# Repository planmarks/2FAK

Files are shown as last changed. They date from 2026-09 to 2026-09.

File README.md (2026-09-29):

<div align="center">

# 2FAK

**Open-source USB-A security key — FIDO2 / WebAuthn, passkeys, and an optional on-board secure element.**

_by muru.global_







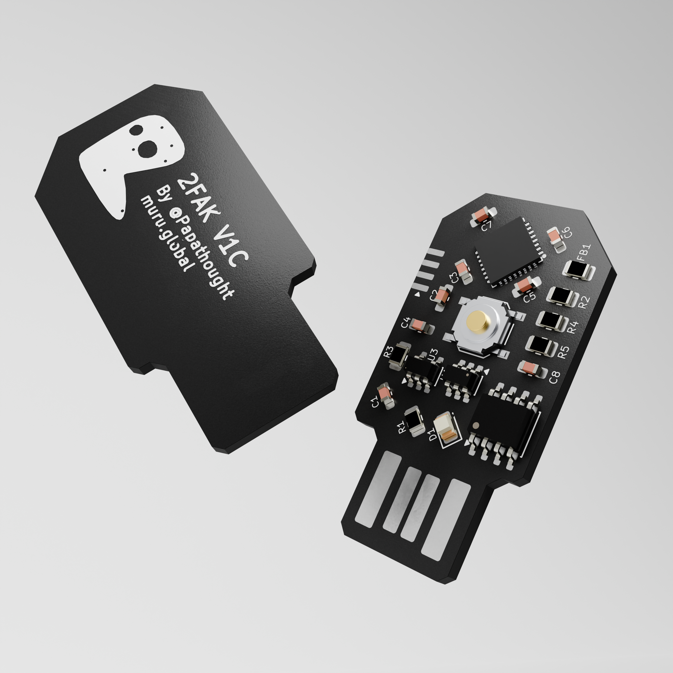
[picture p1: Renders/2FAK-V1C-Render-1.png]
2FAK V1C 3D render — front branding and populated back with the USB-A blade


<sub>2FAK V1C — the board <em>is</em> the USB-A plug: no cable, no moving connector.</sub>

</div>

---

2FAK is a small, affordable, fully open-source hardware security key. Plug it into any USB-A
port, tap the button, and you are signed in — the private keys are generated and kept on the
device and never leave it, so a fake login page or a stolen laptop gets nothing. It is built
on an STMicroelectronics **STM32L442KCU6** with an optional **ATECC608B** secure element.

- **USB VID/PID:** `0x1209 / 0x2FA2` (0x1209 is the pid.codes open-source Vendor ID; PID 0x2FA2 is registered to us)
- **AAGUID:** `c2aa81f8-352d-56e2-c689-2bfdb5a52ccc`
- **Firmware lineage:** fork of Nitrokey FIDO2 / SoloKeys solo1 (see `NOTICE`)

## Highlights

- 🔐 **Phishing-resistant** FIDO2 / WebAuthn — your login is bound to the real site.
- 🗝️ **Passkeys** — go fully passwordless on the Resident firmware (up to ~50 discoverable credentials).
- 🧩 **The board is the plug** — USB-A male blade, no cable, nothing to wear out.
- 🛡️ **Optional secure element** (ATECC608B) holds a device root that can't be read out.
- ✍️ **Signed USB firmware updates** + irreversible **RDP-2** debug lockdown on production units.
- 💻 **Doubles as a hardware SSH key** — see [Hardware SSH Keys](#hardware-ssh-keys).
- 📖 **Open source** (Apache-2.0) and **open hardware** — inspect everything.

<div align="center">
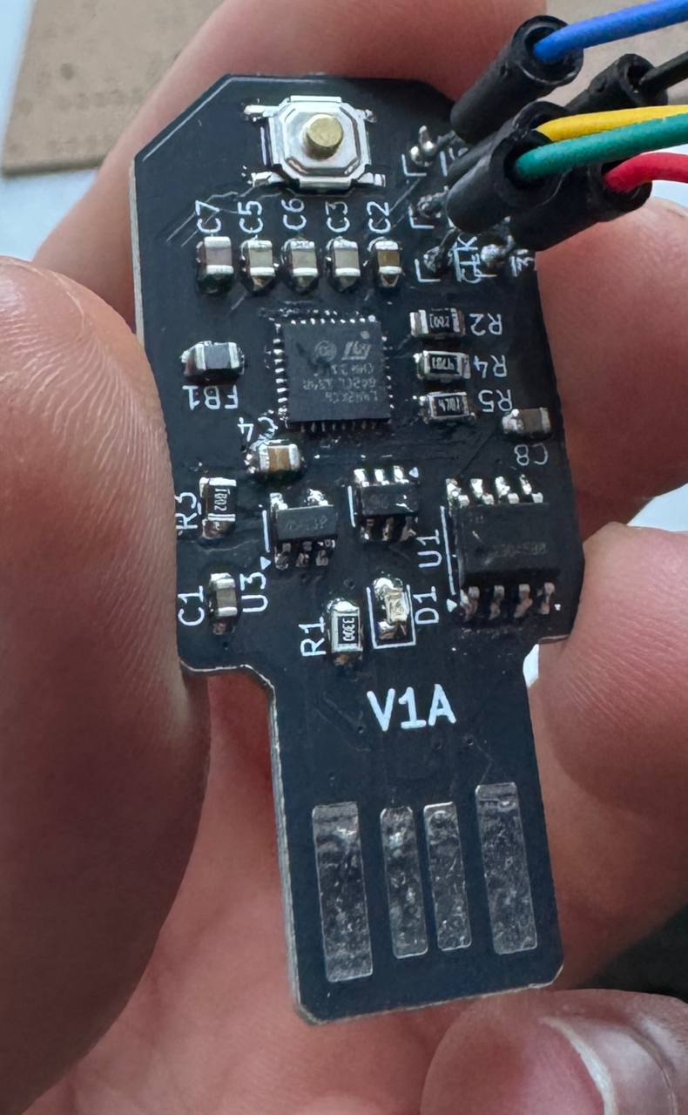
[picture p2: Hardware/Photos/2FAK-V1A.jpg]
2FAK V1A assembled board

<br><sub>Assembled 2FAK (V1A).</sub>
</div>

## Firmware editions

One board, two shipping firmware editions built from a single codebase:

| | **2FAK Secure** (Non-Resident) | **2FAK Passkey** (Resident) |
|---|---|---|
| Model | Second factor (server-side credentials) | Passkeys (discoverable credentials) |
| Discoverable credentials (rk) | No | Yes |
| Credential Management | No | Yes |
| ClientPIN protocols | 1 | 1 and 2 |
| Extensions | hmac-secret, credProtect | hmac-secret, credProtect, minPinLength |
| Conformance (self-test) | CTAP2.0, CTAP2.1 | CTAP2.0, CTAP2.1, CTAP2.3 |
| Hardware SSH keys | `ecdsa-sk` (non-resident) | `ecdsa-sk` incl. **resident/portable** |

Conformance is validated against the **FIDO Alliance Conformance Test Tools (self-test)** and
recorded per firmware under `Firmware/.../tests/`. Formal FIDO Certification is a separate
submission and is **not** claimed.

## Hardware

<div align="center">
<table>
<tr>
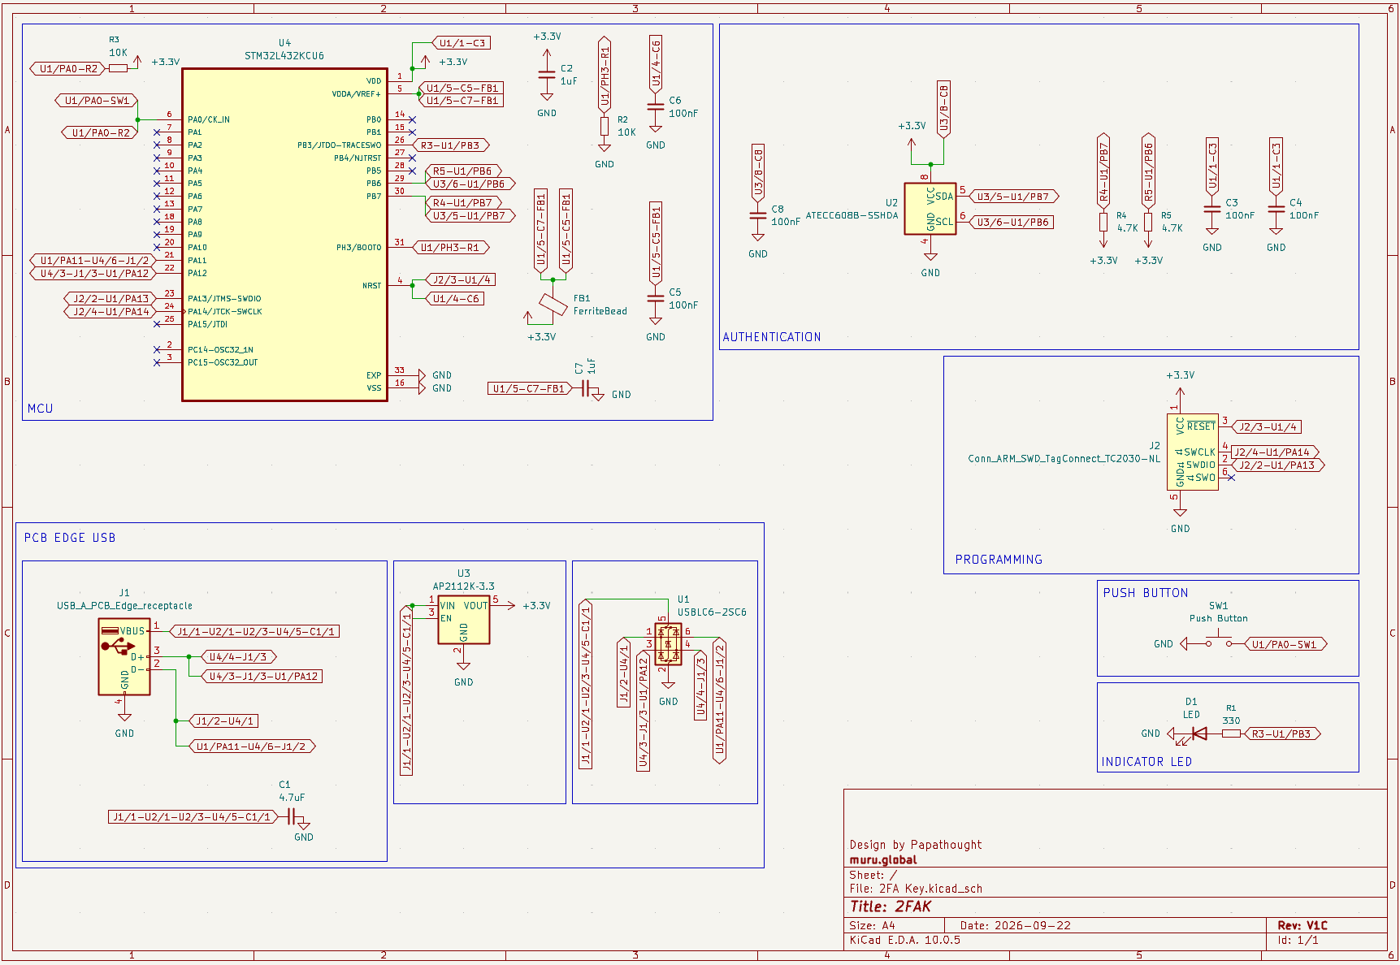
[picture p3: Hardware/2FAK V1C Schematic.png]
2FAK V1C schematic
<td align="center"><br><sub>Schematic (V1C)</sub></td>
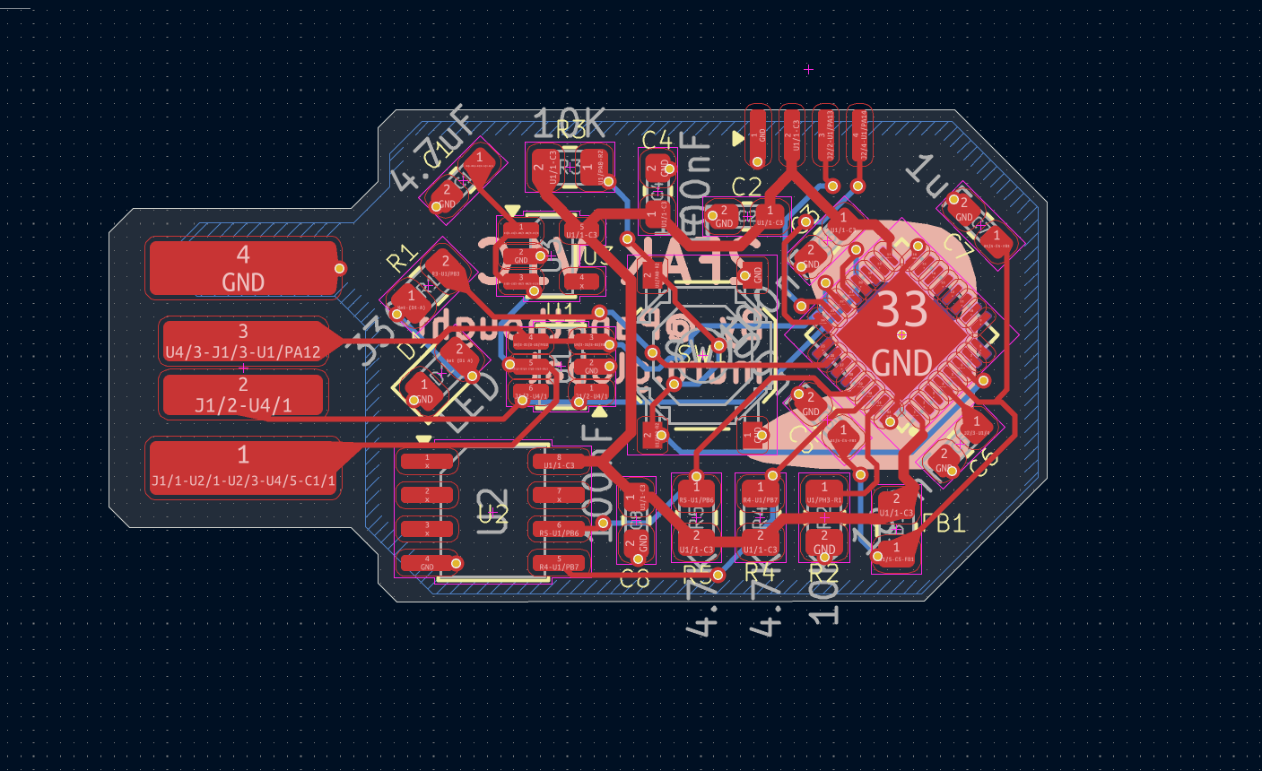
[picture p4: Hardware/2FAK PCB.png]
2FAK PCB layout / X-ray view
<td align="center"><br><sub>PCB layout — X-ray view (V1C)</sub></td>
</tr>
</table>
</div>

### At a glance

| | |
|---|---|
| **MCU** | STM32L442KCU6 — Arm Cortex-M4F, 80 MHz, UFQFPN-32; 256 KB flash / 64 KB SRAM |
| **Secure element** | Microchip ATECC608B on I2C1 (populated variant) |
| **Interface** | USB 2.0 Full-Speed, USB-A male blade (no cable) |
| **Protocols** | FIDO2 / WebAuthn, CTAP2.0 / 2.1 / 2.3 |
| **USB ID** | 0x1209 / 0x2FA2 (pid.codes) |
| **Controls** | Tactile touch button + status LED |
| **Power** | USB bus-powered, ~30 mA, no battery |
| **Size** | ~48 × 21 mm |

<details>
<summary><strong>Full hardware details & pinout</strong></summary>

#### Microcontroller

- **Part:** STM32L442KCU6 (Arm Cortex-M4F, up to 80 MHz, UFQFPN-32). Register-compatible
  with the STM32L432.
- **Memory:** 256 KB flash, 64 KB SRAM.
- **On-chip security:** true random number generator (TRNG), AES-256 hardware accelerator,
  and flash read-out protection (RDP) supported in silicon.
- **Clocking:** crystal-less USB using the internal HSI48 oscillator with the Clock Recovery
  System (CRS); no external crystal required.

#### Secure element (populated variant)

- **Part:** Microchip ATECC608B, on the I2C1 bus.
- Confirmed on hardware at 7-bit I2C address 0x60, Info revision word 0x00006003 (identifies
  an ATECC608B).
- Provides tamper-resistant key storage; on fitted units it holds a device root that cannot
  be read back out of the chip. On boards where it is not fitted, the footprint remains
  unpopulated.

#### USB / UI / power / debug

- USB 2.0 **Full-Speed** (12 Mbit/s) device; **USB-A male** contacts integrated into the PCB
  edge. Dedicated ESD / TVS protection on D+, D- and VBUS.
- One **tactile push button** (user presence) and one **status LED**.
- **USB bus-powered** from 5 V, regulated on-board to 3.3 V by an LDO. ~30 mA typical, no
  battery.
- **SWD** debug/programming (SWDIO / SWCLK); BOOT0 for boot-mode selection.

*Notice: SWD is closed in units sold as 2FAK Authentication Key.*

#### Pin summary

| Function | Pin |
|---|---|
| Button | PA0 |
| Status LED | PB3 |
| USB D- / D+ | PA11 / PA12 |
| SWD (SWDIO/SWCLK)| PA13 / PA14|
| I2C to ATECC (SCL/SDA) | PB6 / PB7 |
| BOOT0 | PH3 |

Note: PB6 / PB7 are shared between the ATECC I2C bus and an optional debug UART. On the
populated (secure-element) boards these pins are used for the I2C bus.

</details>

## Building

Each firmware directory is self-contained. On Windows with the STM32CubeIDE toolchain, from
Git Bash:

```bash
cd "Firmware/Resident CTAP2.3"
bash build.sh                    # production-style build
```

Build switches (environment variables) are documented in `build.sh`. Artifacts land in
`prebuilt/` and are **not** committed (see [Security](#security) below).

## Security

Per-credential keys are generated and held in the MCU; the optional device root can be held
in the ATECC608B secure element. Production units enable flash read-out protection (RDP) and
a verifying bootloader so firmware cannot be extracted or replaced off a locked device.

> **This is a public repository. It never contains private keys.** The following are
> git-ignored and must exist only on the build/flashing machines:
> - muru attestation private keys (`keys/2fak/ca_key.pem`, `att_key.pem`, `priv.bin/.hex`)
> - the production verifying-bootloader signing key
> - any provisioned `*.hex` (a provisioned image embeds the attestation private key)

Public certificates (root CA + leaf), the AAGUID, and the metadata statements are published
on purpose. Release firmware images are distributed via signed GitHub Releases, not committed
to the tree.

## Hardware SSH Keys

The **2FAK Passkey (Resident)** firmware doubles as a hardware-backed SSH key — no extra
firmware needed. SSH's `ecdsa-sk` key type rides on the standard FIDO2 flow, so the private
key stays on the 2FAK and every connection requires a physical touch.

```bash
ssh-keygen -t ecdsa-sk -O resident -O application=ssh:prod -f ~/.ssh/id_ecdsa_sk_prod
```

Because the key is *resident*, you can carry it on the token and pull it onto any machine
with `ssh-keygen -K` — handy for admins working across bastions and multiple workstations.
Add `-O verify-required` to also require the device PIN on privileged hosts. Requires OpenSSH
8.2+; uses ES256 (`ecdsa-sk`), not `ed25519-sk`.

Full sysadmin workflow — portable keys, ProxyJump bastions, Ansible `authorized_keys`, SSH-CA
integration, PIN tiering, Windows/PuTTY, backup enrollment, and the `2FAK-ssh-enroll` helper —
is in [`2FA Docs/2FAK Resident - Hardware SSH Key Guide.md`](2FA%20Docs/2FAK%20Resident%20-%20Hardware%20SSH%20Key%20Guide.md).

## Platform compatibility

Community/self-tested results. "not tested" simply means we haven't checked it yet.

<details>
<summary><strong>Show compatibility matrix</strong></summary>

| Platform | 2FAK Non-Resident | 2FAK Resident |
|---|---|---|
| Google | confirmed | confirmed |
| Microsoft | not supported | confirmed |
| Apple ID | not supported* | not supported* |
| Amazon | not supported | confirmed |
| Facebook / Meta | not tested | not tested |
| X | not tested | not tested |
| GitLab | not supported | confirmed |
| AWS (IAM / root) | unknown error* | unknown error* |
| Cloudflare | confirmed | confirmed |
| Okta | not tested | not tested |
| Bitwarden | not tested | not tested |
| 1Password | not tested | not tested |
| PayPal | not tested | not tested |
| Stripe | not supported | confirmed |
| Coinbase | not tested | not tested |
| Kraken | not tested | not tested |
| Binance | not tested | not tested |
| Dropbox | confirmed | confirmed |
| Proton (Mail) | confirmed | confirmed |
| Fastmail | confirmed | confirmed |
| Nextcloud | not tested | not tested |
| Discord | confirmed | confirmed |
| Salesforce | not tested | not tested |

<sub>* Apple ID and AWS entries reflect platform-side behaviour we're still investigating.</sub>

</details>

## Other firmware options

The programmable (no-secure-element) board can also run:

- Mouse Jiggler firmware *(coming soon)*
- HID Injection firmware *(coming soon)*

## License

Licensed under **Apache-2.0**. See [`LICENSE-APACHE`](LICENSE-APACHE) for the full license
text and `NOTICE` for third-party attribution.

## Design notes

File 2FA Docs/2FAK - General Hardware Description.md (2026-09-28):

# 2FAK - General Hardware Description

General description of the 2FAK hardware platform. This document covers the hardware only;
it makes no reference to firmware or firmware behaviour.

## Overview

2FAK is a small open-source USB-A hardware token. The printed circuit board itself forms
the USB-A plug (a single-piece "blade"), so there is no cable and no separate connector to
wear out. It is built around an STMicroelectronics STM32L4 microcontroller and is powered
entirely from the USB port.

The same board is produced in two hardware configurations:

- **With secure element** - the ATECC608B is populated. Used for the pre-programmed
  security-key units.
- **Without secure element** - the ATECC608B footprint is left unpopulated. Used for the
  programmable units.

Both configurations are otherwise identical.

## Microcontroller

- **Part:** STMicroelectronics STM32L442KCU6 (Arm Cortex-M4F, up to 80 MHz, UFQFPN-32
  package). Register-compatible with the STM32L432.
- **Memory:** 256 KB flash, 64 KB SRAM.
- **On-chip security features:** true random number generator (TRNG), AES-256 hardware
  accelerator, and flash read-out protection (RDP) supported in silicon.
- **Clocking:** crystal-less USB using the internal HSI48 oscillator with the Clock
  Recovery System (CRS); no external crystal is required.

## Secure element (populated variant)

- **Part:** Microchip ATECC608B, on the I2C1 bus.
- Confirmed on hardware at 7-bit I2C address 0x60, Info revision word 0x00006003 (which
  identifies an ATECC608B).
- Provides tamper-resistant key storage and cryptographic operations. On the units where
  it is fitted, it can hold a device root that cannot be read back out of the chip.
- On boards where it is not fitted, the footprint remains but is unpopulated.

## USB interface

- USB 2.0 **Full-Speed** (12 Mbit/s) device.
- **USB-A male** contacts integrated into the edge of the PCB (no cable, no moving
  connector).
- Dedicated ESD / TVS protection on the D+, D- and VBUS lines.

## User interface

- One **tactile push button** (user-presence / control input).
- One **status LED**.

## Power

- **USB bus-powered** from the 5 V supply, regulated on-board to 3.3 V by an LDO.
- Typical current draw about 30 mA. No battery and no battery sensing.

## Debug and programming

- **SWD** debug/programming interface (SWDIO / SWCLK), broken out to a Tag-Connect
  TC2030-style footprint for factory and advanced use.
- BOOT0 is available for boot-mode selection.

## Pin summary

| Function | Pin |
|---|---|
| Button | PA0 |
| Status LED | PB3 |
| USB D- / D+ | PA11 / PA12 |
| SWD (SWDIO/SWCLK)| PA13 / PA14|
| I2C to ATECC (SCL/SDA) | PB6 / PB7 |
| BOOT0 | PH3 |

Note: PB6 / PB7 are shared between the ATECC I2C bus and an optional debug UART. On the
populated (secure-element) boards these pins are used for the I2C bus.

## Board

- 2-layer FR4, ground-poured.
- Approximately 48 x 21 mm.
- Gold-plated USB edge contacts.
- Hardware revision V1A.

## Operating conditions

- Works in any standard USB-A port. Driver-free at the hardware level (enumeration and
  behaviour are determined by whatever firmware is loaded, which is out of scope here).

*Hardware revision V1A. Specifications may change.*

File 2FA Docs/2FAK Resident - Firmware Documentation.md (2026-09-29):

# 2FAK Resident - Firmware Documentation

Documentation of the **resident (passkey)** firmware. This document covers the firmware only.
It is one of two firmware variants built from a single codebase; the second-factor variant is
documented in `2FAK Non-Resident - Firmware Documentation.md`. This variant is the same code
built with `RESIDENT=1` (and `FIDO23=1`).

## Summary

A FIDO2 / WebAuthn security-key firmware that supports **discoverable credentials (passkeys)**
and on-device **credential management**, for passwordless sign-in. It is a fork of the Nitrokey
FIDO2 firmware, which derives from SoloKeys Solo 1.

- **Transport:** USB HID (CTAPHID).
- **USB identity:** VID 0x1209 (pid.codes, open-source) / PID 0x2FA2.
- **AAGUID:** c2aa81f8-352d-56e2-c689-2bfdb5a52ccc (self-assigned).
- **Conformance:** passes the FIDO Alliance Conformance Test Tools for CTAP2.0, CTAP2.1 and
  CTAP2.3 (self-test). See `2FAK Resident - FIDO Conformance Readiness.md`.
- **License:** Apache-2.0.

## Protocols advertised (authenticatorGetInfo)

- **versions:** `FIDO_2_0`, `FIDO_2_1_PRE`, `FIDO_2_1`, `FIDO_2_3`.
- **extensions:** `credProtect`, `hmac-secret`.
- **options:** `rk = true`, `up = true`, `plat = false`, `credMgmt = true`, `clientPin`
  (dynamic), `pinUvAuthToken = true`. Emitted in CTAP2 canonical key order.
- **pinUvAuthProtocols:** `[1, 2]`.
- **transports:** `["usb"]`.
- **algorithms:** ES256 (`-7`).
- **maxCredentialCountInList**, **maxCredentialIdLength**, **minPINLength** (4),
  **firmwareVersion**.

## Credential model

- **Resident / discoverable credentials (passkeys).** `authenticatorMakeCredential` with
  `rk = true` stores the credential on the device so it can be found later by a
  getAssertion with an empty allow-list (passwordless sign-in). Capacity is up to
  approximately **50 resident credentials**.
- Discoverable credentials are flagged inside the (MAC-covered) credential ID. Once a
  discoverable credential is deleted via credential management, a getAssertion that presents
  its credential ID in an allow-list correctly fails with `NO_CREDENTIALS` (a deleted passkey
  cannot be resurrected).
- Non-discoverable (second-factor) credentials also work, exactly as in the non-resident
  variant.

## CTAP commands

- Everything in the non-resident variant, plus:
- `authenticatorCredentialManagement` (0x0A / preview 0x41): `getCredsMetadata`,
  `enumerateRPs` (Begin/GetNextRP), `enumerateCredentials` (Begin/GetNextCredential),
  `deleteCredential`, and `updateUserInformation`.
- `authenticatorSelection` (0x0B).
- **Client PIN:** PIN/UV auth protocols **1 and 2**, including
  `getPinUvAuthTokenUsingPinWithPermissions`.
- **pinUvAuthToken:** 32-byte token; permission bits makeCredential + getAssertion +
  **credentialManagement** (`mc`, `ga`, `cm`); optional RP-ID binding; rolling ~30 s
  inactivity lifetime; invalidated on power cycle and reset. Credential-management commands
  require a token carrying the `cm` permission; a token without it is rejected with
  `PIN_AUTH_INVALID`.

## Client PIN behaviour

- Same as the non-resident variant: optional by default, with build-time `PIN_POLICY`
  (`optional` / `requireset` / `alwaysuv`). Standard CTAP retry handling (per-boot lockout at
  3 consecutive failures, full block at zero retries; a reset clears both).

## User presence

- A physical button press is required for registration, authentication, and
  `authenticatorSelection`, with LED signalling.

## Extensions

- **hmac-secret** (protocol 1 and 2 aware).
- **credProtect** (credential-protection levels; the level is also reported through
  credential management).

## Hardware SSH keys (OpenSSH)

Because SSH's FIDO key types ride on the standard FIDO2 credential flow, this firmware works
as a hardware-backed SSH key with **no firmware changes**:

- OpenSSH 8.2+ `ecdsa-sk` keys use ES256, which is exactly what this firmware advertises;
  the FIDO application string `ssh:` is treated as an ordinary RP ID (no RP-ID filtering).
- **Resident (portable) SSH keys** (`ssh-keygen -t ecdsa-sk -O resident`) are supported
  because this variant stores discoverable credentials; they can be pulled onto any machine
  with `ssh-keygen -K`. The non-resident variant can only do non-resident `ecdsa-sk` keys.
- `verify-required` maps to the device PIN (Client PIN) plus the touch (user presence).
- `ed25519-sk` is **not** supported (no Ed25519/EdDSA in the firmware); use `ecdsa-sk`.

Full sysadmin workflow (resident enroll/export, ProxyJump bastions, Ansible
`authorized_keys`, SSH-CA integration, PIN tiering, Windows/PuTTY, backup enrollment, and
the `2FAK-ssh-enroll` helper) is documented in `2FAK Resident - Hardware SSH Key Guide.md`.

## Attestation

- Packed / `basic_full` attestation, muru.global batch attestation key + certificate on
  production units (injected by `provision_attestation.py`); metadata statement embeds the
  muru Root CA. Not FIDO Certified; conformance is a self-test result; not (yet) in the FIDO
  Metadata Service.

## Secure firmware update, production lockdown, and hardware root

These are identical to the non-resident variant:

- **Signed USB update:** the verifying (production) bootloader accepts only muru-signed
  firmware (ECDSA P-256 over the app region); the dev bootloader accepts unsigned firmware;
  anti-rollback enforces version-not-older.
- **Production lockdown:** RDP-2 permanently disables the debug port; signed USB updates still
  work afterwards; production images are built without `SOLO_HACKER`.
- **Hardware root of trust:** on units with a provisioned ATECC608B the FIDO master secret is
  derived inside the secure element, with a transparent software fallback if the chip is
  absent, unprovisioned, or fails.

(See `2FAK Non-Resident - Firmware Documentation.md` for the detailed description of these
shared subsystems.)

## Build (reference)

- `RESIDENT=1 FIDO23=1 bash build.sh` selects the passkey behaviour and advertises `FIDO_2_3`
  (default for this variant).
- `VERIFY_BOOT=1` produces the production image (`all-verifying.hex`); `VERIFY_BOOT=0`
  produces the dev image (`all-dev.hex`).
- Toolchain: arm-none-eabi-gcc + make from the STM32CubeIDE bundle. Flash region use is
  roughly one third of the 256 KB device.

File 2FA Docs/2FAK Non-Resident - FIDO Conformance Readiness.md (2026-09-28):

# 2FAK Non-Resident - FIDO Conformance Readiness

Status of the Non-resident firmware against the FIDO Alliance Conformance Testing Tools
and the Metadata Statement spec (v3.0). For the team.

## STATUS: CTAP2.0 and CTAP2.1 authenticator tests PASS

Using `prebuilt/all_conformance.hex` + `metadata/2fak_metadata.json`, the FIDO
Conformance Tools v1.9.2 CTAP2.0 and CTAP2.1 authenticator suites pass for the
non-resident profile (resident-key / enterprise / largeBlob / credMgmt / authrConfig /
bioEnroll modules are out of scope for this SKU and not selected). This is self-test
validation, not formal FIDO certification. Remaining work is administrative (see end).

## What the tools actually check

1. CTAP2 authenticator conformance - tests the device against the CTAP spec, up to the
   highest version it advertises in getInfo.
2. Metadata Statement validation - checks the statement is well-formed and that its claims
   (algorithms, attestation, key protection, AAGUID) match the device, and that device
   attestation chains to the declared `attestationRootCertificates`.

Formal certification and Metadata Service (MDS) listing are a separate, paid FIDO
process. The tools themselves can be used for self-testing.

## Done in firmware / tooling

- CTAP2 command set: GetInfo, MakeCredential, GetAssertion, ClientPIN, Reset; extensions
  hmac-secret and credProtect; non-resident model (rk=false, resident requests rejected).
- PIN/UV Auth Protocol 1 and 2; pinUvAuthToken permissions model
  (getPinUvAuthTokenUsingPinWithPermissions, mc/ga permission bits, RP-ID binding,
  rolling expiry). Validated on hardware.
- 2.3 getInfo fields present: algorithms, minPINLength, firmwareVersion, pinUvAuthToken,
  transports, maxCredentialCountInList, maxCredentialIdLength.
- **Version advertisement is now a build switch.** Default tops out at `FIDO_2_1` (which
  we conform to). `FIDO23=1` additionally advertises `FIDO_2_3`. This matters because the
  tools test to the highest advertised version: shipping FIDO_2_3 before full 2.3
  conformance would fail.
- **Attestation PKI created.** `keys/make_attestation_ca.py` builds a self-signed
  attestation Root CA and a batch leaf certificate. The leaf carries the AAGUID extension
  (1.3.6.1.4.1.45724.1.1.4) equal to the device AAGUID `c2aa81f8-352d-56e2-c689-2bfdb5a52ccc`,
  Basic Constraints CA:FALSE, OU="Authenticator Attestation". Chain verifies. This fixes
  the earlier bug where the leaf cert's AAGUID did not match getInfo.
- **Metadata statement drafted.** `metadata/make_metadata.py` emits
  `metadata/2fak_metadata.json` (schema 3), mirroring the default build's getInfo and
  embedding the Root CA in `attestationRootCertificates`.

## Required Metadata Statement fields - status

| Field | Status |
|---|---|
| protocolFamily, schema, upv | done (fido2, 3, [1.0, 1.1]) |
| description, authenticatorVersion | done |
| authenticationAlgorithms, publicKeyAlgAndEncodings | done (ES256, cose) |
| attestationTypes | basic_full |
| userVerificationDetails | presence_internal / passcode_internal |
| keyProtection, matcherProtection | hardware / on_chip |
| tcDisplay, attachmentHint, cryptoStrength | done |
| aaguid | done, consistent across firmware + cert + statement |
| attestationRootCertificates | done (real Root CA) |
| authenticatorGetInfo | mirrors default build |
| legalHeader | present, but ACCEPTING it is a vendor legal decision (see below) |

## Conformance-blocking work - now DONE

1. **Real attestation provisioned.** `provision_attestation.py` injects the muru batch leaf
   cert (chaining to the Root CA embedded in the metadata) so device attestation validates.
   Production units ship attested; the dev image no longer relies on the Solo "hacker" key.
2. **CTAP2 conformance tools run and passing.** The CTAP2.0 and CTAP2.1 authenticator suites
   pass for this SKU (self-test) using `prebuilt/all_conformance.hex` + the metadata
   statement. The run history (error codes, option matrix, CBOR canonical encoding,
   absent-feature responses, PIN code-point length) is in the "run" sections below.
3. **PIN policy.** Shipped default is `optional` (build-time `PIN_POLICY`); metadata
   `userVerificationDetails` matches (presence + passcode).

## Vendor / business steps

- **USB VID/PID registered:** VID 0x1209 (pid.codes) / PID 0x2FA2. The pid.codes
  allocation PR has been approved and merged, so PID 0x2FA2 is officially recorded to us.
- Keeping `keys/2fak/ca_key.pem` (the attestation Root CA private key) safe and backed
  up. It is gitignored. Losing it means re-issuing the CA and re-provisioning devices.
- Accepting the FIDO `legalHeader` terms and creating a FIDO account - only needed for the
  paid path below.
- Formal FIDO certification + MDS submission (the paid path) and, if desired, registering
  the AAGUID - planned for later, not required to ship.

## For full CTAP 2.3 (optional, later)

Before enabling `FIDO23=1` for shipping: implement the remaining 2.3 items
(alwaysUv/makeCredUvNotRqd handling as advertised, full up/uv option matrix,
authenticatorConfig / setMinPINLength if claimed) and pass the 2.3 conformance profile.

## First CTAP2.0 conformance run (findings + fixes)

First run: 23 pass / 25 fail. Root causes and fixes:

1. **authenticatorReset 10-second window (caused ~9 failures).** The tool resets the
   authenticator programmatically in most "before all" hooks; our production firmware only
   allows Reset within 10s of power-up, so later resets returned CTAP2_ERR_NOT_ALLOWED and
   cascaded. FIX: `CONFORMANCE=1` build flag lifts the window (reset allowed any time,
   touch still required). Use `prebuilt/all_conformance.hex` for testing; production keeps
   the 10s window.
2. **Metadata P-22 attachmentHint** - "external" must be combined with a transport flag.
   FIX: now `["external", "wired"]`.
3. **Metadata P-29 icon** - the tool requires an `icon`. FIX: a valid PNG data URL is now
   generated.
4. **authenticatorGetInfo deep-equality** - metadata must match the device getInfo exactly.
   FIX: added `maxCredentialCountInList` (20) and `maxCredentialIdLength` (128).
5. **HIDFORK TIMEOUT / "Sequence out of order"** - the tool's own node-HID transport on
   Windows, not the device: python-fido2 (a strict implementation) drives the same device
   flawlessly. Mitigations: direct USB port (no hub), close every other app using the key
   (browser, our python scripts, Windows "Security key" settings), and if Windows stays
   flaky run the conformance tool on Linux. The reset fix also clears hung states between
   groups, which removes many secondary timeouts.

Re-test with `prebuilt/all_conformance.hex` flashed and the regenerated
`metadata/2fak_metadata.json` loaded.

## Second run (31 pass / 34 fail) - findings + fixes

The reset fix + metadata fixes worked (getInfo, metadata statement, user-entity checks
now pass). New/remaining:

1. **User presence timeouts (biggest, ~15 failures).** The tool issues many
   makeCredential/getAssertion ops; each waited for a physical touch, timed out
   (HIDFORK TIMEOUT), and left the channel busy (CTAP1_ERR_CHANNEL_BUSY cascade on the
   following F-tests). FIX: the CONFORMANCE build now auto-approves user presence
   (`ctap2_user_presence_test` returns success immediately) so the suite runs unattended.
   Production still requires a real touch.
2. **Metadata P-3 passcode_external.** For a ClientPin authenticator the tool requires a
   userVerificationDetails entry of `passcode_external` (the PIN is entered on the client
   and sent to the authenticator). FIX: changed `passcode_internal` -> `passcode_external`.
3. **Resident-key / CredProtect tests will still fail - expected.** The selected "Full
   feature profile" creates *discoverable credentials*; this is a non-resident device
   (`rk=false`), so those return CTAP2_ERR_UNSUPPORTED_OPTION. Select the profile WITHOUT
   Discoverable Credentials, or accept that RK/credProtect-on-RK tests do not apply to
   this SKU. Passing them would require the Resident firmware variant.
4. **"Sequence out of order" on getKeyAgreement (2 groups).** Under investigation; the
   same command works perfectly via python-fido2, so it is likely the tool's node-HID
   transport. Re-check after the auto-UP fix clears the channel-busy cascade.

## Third run (108 pass / 9 fail) - findings + fixes

Huge jump. The 9 remaining, categorized:

- **HID-1 P-10 (keepalive / cancel) - FIXED** via `SKIP_BUTTON_CHECK_WITH_DELAY`
  (CONFORMANCE_BUILD): emits keepalives and honours CTAPHID_CANCEL for ~500ms, then
  auto-approves.
- **HID-1 P-11 (getAssertion invalid credId -> keepalive then NO_CREDENTIALS) - FIXED in
  logic.** getAssertion returned NO_CREDENTIALS *before* the user-presence step, so no
  keepalive was emitted (SKIP_WITH_DELAY alone did not help because UP was never reached).
  Now a user-presence test runs before returning NO_CREDENTIALS (emits the keepalive and
  avoids credential-existence timing leaks).
- **CredProtect P-1/P-2/P-3 - not applicable to this SKU.** They create *discoverable
  credentials*; this is non-resident (`rk=false`) so they return
  CTAP2_ERR_UNSUPPORTED_OPTION. Select the profile WITHOUT Discoverable Credentials.
  These cannot pass without the Resident firmware variant.
- **ClientPin GetRetries P-3 - procedural.** The test exhausts PIN retries to reach
  CTAP2_ERR_PIN_BLOCKED (0x32). Our per-boot lockout returns 0x34 after 3 wrong attempts
  and requires a real power cycle to continue (both behaviours are CTAP-mandated and P-2,
  which needs 0x34, passes). When the tool prompts after 0x34 during THIS test, physically
  unplug/replug so it can continue to 0x32.
- **3 x "Timeout of 30000ms" (MakeCred-Req-3, GetAssertion-Req-3, Reset-1 before-all
  hooks) - likely intermittent HID.** No CTAP error was returned; the hook hung. Re-check
  after the keepalive fix (device stays responsive during UP) and with a clean HID
  environment. If they persist, capture which command hangs.

## CTAP2.1 run - findings + fixes

CTAP2.0 fully passed. CTAP2.1 findings (all fixed in firmware; general 2.1 correctness,
in both default and conformance builds):

1. **authenticatorSelection (0x0B) - implemented.** Was unhandled (P-15 got no keepalive).
   Added the command: it runs a user-presence check (keepalive + CANCEL), returns OK on
   touch / KEEPALIVE_CANCEL on cancel.
2. **makeCredential up=true rejected -> accepted.** We advertise the `up` option, so the
   tool sends makeCredential with up=true and expects success. We now accept explicit
   up=true (reject only up=false).
3. **hmac-secret not PIN-protocol-2 aware -> fixed.** getAssertion hmac-secret returned
   INVALID_LENGTH under protocol 2 (48/80-byte saltEnc with IV). The extension is now
   protocol-aware: HKDF shared secret, 32-byte saltAuth, IV strip on decrypt, IV prepend
   on the encrypted output. Struct/parser widened to 80 bytes + a pinProtocol field.
4. **hmac-secret wrong-type accepted -> rejected.** makeCredential with a non-boolean
   hmac-secret now returns CTAP2_ERR_INVALID_CBOR_TYPE (F-1).

Second CTAP2.1 pass - further findings + fixes:

5. **hmac-secret protocol-2 two-salt output overflowed the getAssertion extensions
   buffer (INVALID_CBOR).** The buffer was 80 bytes; a protocol-2 two-salt output encodes
   to ~95 bytes (IV+64+CBOR). Enlarged `getAssertionState.buf.extensions` to 128. Fixes
   HMAC-Secret P-3 (which also sends a two-salt request) and P-4.
6. **Metadata P-36 legalHeader.** MDS3 requires the exact string "Submission of this
   statement ... https://fidoalliance.org/metadata/metadata-legal-terms/." (not the URL).
   Fixed in make_metadata.py.
7. **ClientPin F-4 (min PIN length by code points) - FIXED.** On a clean run this was a
   real defect: our PIN length check was byte-based, so a 3-code-point multi-byte PIN
   (>= 4 bytes) was wrongly accepted and set, and a follow-up setPIN then returned
   NOT_ALLOWED. CTAP requires a minimum of 4 Unicode CODE POINTS. ctap_update_pin_if_verified
   now counts code points (skipping UTF-8 continuation bytes) and rejects < 4 with
   PIN_POLICY_VIOLATION. Applies to both protocol 1 and 2.

Environmental / procedural (not firmware): "Waited too long to connect" and "FORCED
TERMINATION" are the HID transport / a manual stop; the PIN-retry test still needs
physical replugs to reach 0x32.

## Images

- `prebuilt/all.hex` - production default (FIDO_2_1, reset-restricted).
- `prebuilt/all_attested.hex` - production default + muru attestation.
- `prebuilt/all_conformance.hex` - CONFORMANCE build (reset any time) + attestation. Flash
  this for the FIDO conformance tools. **Do not ship it.**

## Reproduce

    python keys/make_attestation_ca.py       # one-time: create the attestation CA
    python metadata/make_metadata.py         # regenerate the metadata statement
    bash build.sh                            # default: FIDO_2_1, U2F off, PIN optional
    python provision_attestation.py prebuilt/all.hex prebuilt/all_attested.hex

    # Conformance-test image (reset allowed any time) + attestation:
    CONFORMANCE=1 bash build.sh
    python provision_attestation.py prebuilt/all.hex prebuilt/all_conformance.hex
    bash build.sh                            # rebuild the production default afterwards

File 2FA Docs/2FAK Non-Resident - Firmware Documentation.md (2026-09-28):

# 2FAK Non-Resident - Firmware Documentation

Documentation of the **non-resident (second-factor)** firmware. This document covers the
firmware only. It is one of two firmware variants built from a single codebase; the passkey
variant is documented in `2FAK Resident - Firmware Documentation.md`.

## Summary

A FIDO2 / WebAuthn security-key firmware configured as a **second factor only**. It creates
non-discoverable (server-side) credentials and declines requests to store resident /
discoverable credentials. It is a fork of the Nitrokey FIDO2 firmware, which derives from
SoloKeys Solo 1, and is built with the `RESIDENT=0` option.

- **Transport:** USB HID (CTAPHID).
- **USB identity:** VID 0x1209 (pid.codes, open-source) / PID 0x2FA2.
- **AAGUID:** c2aa81f8-352d-56e2-c689-2bfdb5a52ccc (self-assigned).
- **Conformance:** passes the FIDO Alliance Conformance Test Tools for CTAP2.0 and CTAP2.1
  (self-test). See `2FAK Non-Resident - FIDO Conformance Readiness.md`.
- **License:** Apache-2.0.

## Protocols advertised (authenticatorGetInfo)

- **versions:** `FIDO_2_0`, `FIDO_2_1_PRE`, `FIDO_2_1` (this variant does not advertise
  `FIDO_2_3`).
- **extensions:** `credProtect`, `hmac-secret`.
- **options:** `rk = false`, `up = true`, `plat = false`, `clientPin` (dynamic, reflects
  whether a PIN is set), `pinUvAuthToken = true`. No `credMgmt`.
- **pinUvAuthProtocols:** `[1, 2]`.
- **transports:** `["usb"]`.
- **algorithms:** ES256 (`-7`).
- **maxCredentialCountInList**, **maxCredentialIdLength**, **minPINLength** (4),
  **firmwareVersion**.

## Credential model

- **Non-resident only.** `authenticatorMakeCredential` returns
  `CTAP2_ERR_UNSUPPORTED_OPTION` when a resident/discoverable credential (`rk = true`) is
  requested. Nothing is stored on the key and there is no account picker; the number of
  accounts is effectively unlimited because credentials live on the relying party.
- Credentials are self-authenticating: the credential ID carries a MAC that the device
  verifies, so per-account key pairs are re-derived on demand and never exported.

## CTAP commands

- `authenticatorGetInfo`, `authenticatorMakeCredential`, `authenticatorGetAssertion`,
  `authenticatorClientPIN`, `authenticatorReset`, plus the Solo/Nitrokey vendor commands
  (bootloader entry, version, lock, ATECC self-test).
- **Client PIN:** PIN/UV auth protocols **1 and 2**, including
  `getPinUvAuthTokenUsingPinWithPermissions`.
- **pinUvAuthToken:** 32-byte token; permission bits limited to makeCredential + getAssertion
  (`mc`, `ga`); optional RP-ID binding; rolling ~30 s inactivity lifetime; invalidated on
  power cycle and on reset. A token presented without the permission an operation needs is
  rejected with `PIN_AUTH_INVALID`.

## Client PIN behaviour

- Optional by default (the relying party decides). A build-time `PIN_POLICY` can change this:
  `optional` (default), `requireset` (a PIN must be set before the first credential), or
  `alwaysuv` (advertise `alwaysUv` and require a pinUvAuthToken on every operation).
- Standard CTAP retry handling: a per-boot lockout after 3 consecutive bad attempts
  (`PIN_AUTH_BLOCKED`, cleared by a power cycle), and a full block when the persistent retry
  counter reaches zero (`PIN_BLOCKED`, cleared only by an authenticatorReset). A reset also
  clears the per-boot lockout.

## User presence

- A physical button press is required for registration and authentication (user presence),
  with LED signalling (idle off, waiting blink, accepted solid).

## Extensions

- **hmac-secret** (protocol 1 and 2 aware).
- **credProtect** (credential-protection levels, packed into the MAC-covered credential ID).

## Attestation

- Packed / `basic_full` attestation.
- Development images seed the well-known Solo "hacker" attestation key. Production units are
  provisioned with the muru.global batch attestation key + certificate (injected at flash
  time by `provision_attestation.py`); the metadata statement embeds the muru Root CA.
- The device uses self-/batch attestation and is not (yet) listed in the FIDO Metadata
  Service. It is not FIDO Certified; conformance is a self-test result.

## Secure firmware update over USB

- **Verifying (production) bootloader:** accepts firmware over USB only if it is signed with
  the muru production bootloader key (ECDSA P-256 over a SHA-256 of the application region).
  The private key never leaves muru; the device verifies the signature itself.
- **Non-verifying (dev) bootloader:** accepts unsigned firmware, for development.
- **Anti-rollback:** the verifying bootloader only accepts firmware whose version is greater
  than or equal to the currently installed version.
- Updates are delivered over USB (no programmer needed), so a unit remains updatable after
  its debug port is closed.

## Production lockdown

- Production units enable **flash read-out protection level 2 (RDP-2)**: the SWD/debug port
  is permanently disabled, so firmware and secrets cannot be read out or the chip reflashed
  over a programmer. Signed USB updates still work after locking, because the bootloader
  remains intact.
- Production images are built without the `SOLO_HACKER` option.

## Hardware root of trust (populated units)

- On units with the ATECC608B fitted and provisioned, the FIDO master secret is derived
  inside the secure element (MAC command, mode 0x06) from an unreadable root key, rather than
  held only in MCU flash. Per-credential keys derive from that master secret.
- If the secure element is absent, unprovisioned, or ever fails to derive, the firmware falls
  back to a software master secret with no change in behaviour, so a missing or mis-provisioned
  chip cannot break the FIDO function.
- An authenticatorReset changes the per-device salt, which invalidates all previously derived
  credentials.

## Build (reference)

- `RESIDENT=0 bash build.sh` selects the non-resident behaviour (default for this variant).
- `VERIFY_BOOT=1` produces the production image (`all-verifying.hex`, verifying bootloader,
  `SOLO_HACKER` off); `VERIFY_BOOT=0` produces the dev image (`all-dev.hex`).
- `U2F=1` optionally compiles the legacy U2F/CTAP1 path (off by default to save flash).
- Toolchain: arm-none-eabi-gcc + make from the STM32CubeIDE bundle. Flash region use is
  roughly one third of the 256 KB device.

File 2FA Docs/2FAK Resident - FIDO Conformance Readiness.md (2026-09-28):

# 2FAK Resident - FIDO Conformance Readiness

Status of the **resident (passkey)** firmware against the FIDO Alliance Conformance Testing
Tools and the Metadata Statement spec (v3.0). For the team.

## STATUS: CTAP2.0, CTAP2.1 and CTAP2.3 authenticator tests PASS

The passkey build (`RESIDENT=1 FIDO23=1`, plus the conformance test image) passes the FIDO
Conformance Tools CTAP2.0, CTAP2.1 **and** CTAP2.3 authenticator suites, together with its
metadata statement. This is **self-test validation, not formal FIDO Certification.**

Results (self-test, all zero failures):

| Suite | Result |
|---|---|
| CTAP2.0 | 128 passed / 0 failed |
| CTAP2.1 | 139 passed / 0 failed |
| CTAP2.3 | 180 passed / 0 failed |

The last full run was verified on hardware.

## What the tools check

1. **CTAP2 authenticator conformance** - the device is tested against the CTAP spec up to the
   highest version it advertises in getInfo (`FIDO_2_3` for this build).
2. **Metadata Statement validation** - the statement must be well-formed and its claims
   (versions, options, algorithms, attestation, key protection, AAGUID) must match the
   device's getInfo, and device attestation must chain to the declared
   `attestationRootCertificates`.

Formal certification and Metadata Service (MDS) listing are a separate, paid FIDO process.

## Test modules selected (passkey profile)

Because this build advertises `rk = true` and `credMgmt = true`, the resident-key and
credential-management modules are in scope and are exercised:

- Transports, Generic
- MakeCredential (Request + Response), GetAssertion (Request + Response)
- Reset
- Discoverable Credentials (Resident Key)
- Extensions: HMAC-Secret (incl. strict PUAT2), CredProtect, MinPinLength
- ClientPIN protocol 1 and protocol 2
- Credential Management API (metadata, enumerate RPs, enumerate credentials, update, delete)
- Metadata tests

Not selected / not applicable (not advertised by this SKU): Enterprise Attestation,
Authenticator Config, Biometric Enrollment, Large Blobs.

## Metadata alignment

The metadata statement (`metadata/2fak_metadata.json`) is generated to match the device
getInfo exactly:

- `versions`: `FIDO_2_0`, `FIDO_2_1_PRE`, `FIDO_2_1`, `FIDO_2_3`; `upv` includes `{1,0}`,
  `{1,1}`, `{1,3}`.
- `options`: `rk = true`, `up = true`, `plat = false`, `credMgmt = true`, `clientPin = false`
  (fresh device), `pinUvAuthToken = true`.
- `authenticationAlgorithms`: `secp256r1_ecdsa_sha256_raw`; `attestationTypes`: `basic_full`;
  attestation chains to the muru.global Root CA embedded in the statement.

## Notable fixes made to reach a clean pass

- Advertise `FIDO_2_3` and add `{1,3}` to metadata `upv` for the 2.3 profile.
- Enable resident keys + credential management (rk storage, `credMgmt` option, the `cm`
  pinUvAuthToken permission).
- Implement `updateUserInformation` (credential management 0x07).
- A **deleted discoverable credential must not authenticate** via an allow-list getAssertion:
  discoverable credentials are flagged in the (MAC-covered) credential ID and require a live
  resident record, so a deleted passkey returns `NO_CREDENTIALS`.
- Return `PIN_AUTH_INVALID` (not `UNAUTHORIZED_PERMISSION`) when a *presented* pinUvAuthToken
  lacks the permission an operation needs (mc/ga/cm).
- Clear the per-boot PIN lockout on `authenticatorReset` (the tool resets between modules
  instead of power-cycling).
- Emit a KEEPALIVE before a CANCEL can be observed (HID keepalive/cancel test).

## Test vs production image

Conformance is run with a **conformance build** (`CONFORMANCE=1`) that relaxes two
test-hostile behaviours so the tools can run unattended: user presence is auto-approved after
a short keepalive window, and `authenticatorReset` is allowed at any time (not just within
the first 10 s of power-up). **This image is for testing only and must not ship.** Production
units run the normal image, which requires a real button touch and keeps the reset window.

## Not claimed

- Not FIDO Certified (self-test only).
- Not listed in the FIDO Metadata Service.
- Formal certification / MDS listing is the separate, paid FIDO process, planned for later.

## Reproduce

1. Build the conformance image: `RESIDENT=1 FIDO23=1 CONFORMANCE=1 bash build.sh`, then run
   `provision_attestation.py` so the device presents the muru attestation.
2. Flash the resulting image; load `metadata/2fak_metadata.json` into the tool's metadata
   field.
3. In the FIDO Conformance Tools, select the passkey-profile modules listed above (leave
   Enterprise Attestation, Authenticator Config, Biometric Enrollment and Large Blobs
   unselected).
4. Run each of the CTAP2.0, CTAP2.1 and CTAP2.3 suites.

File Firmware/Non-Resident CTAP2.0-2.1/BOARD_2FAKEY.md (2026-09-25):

# 2FA Key — board port of the Nitrokey FIDO2 firmware

This is the **Nitrokey FIDO2 firmware** (a maintained fork of SoloKeys Solo 1),
with a small board bring‑up applied for the *2FA Key* hardware
(STM32L442KCU6, USB‑A blade, button on PA0, single LED on PB3).

Source cloned from <https://github.com/Nitrokey/nitrokey-fido2-firmware> (branch
`master`) with submodules. The firmware runs on the **STM32L442KC** unchanged —
it is register‑compatible with the L432KC the code targets (L442 = L432 + AES).

---

## What was changed for this board

Only two functional changes were needed — the rest of the reference config already
matches this hardware (crystal‑less HSI48+CRS clock, active‑low button read, SPI on
PA5/6/7 not PB3):

| File | Change | Why |
|---|---|-----|
| `targets/stm32l432/src/app.h` | `HWREV` default `3 → 2` | `HWREV ≤ 2` maps the user‑presence button to **PA0** (SW1). HWREV 3 uses PB1. |
| `targets/stm32l432/Makefile` | `HWREV ?= 3 → 2` | same, for targets that pass `-DHWREV`. (`all-hacker` passes no `-DHWREV`, so the `app.h` default also matters — both are set.) |
| `targets/stm32l432/src/led.c` | `led_rgb()` drives **PB3 GPIO** on/off instead of TIM2 RGB PWM | this board has a single LED (D1) on PB3, not an RGB LED on PA1/2/3. |
| `targets/stm32l432/src/init.c` | `init_gpio()` configures **PB3** as push‑pull output | drive the status LED. |

Things that did **not** need changing (verified in source):
- **Button polarity** — `device.c` already reads the button active‑low
  (`0 == (port & pin)`), matching SW1→GND with the R3 pull‑up. *(The earlier
  `FIRMWARE_PORTING.md` guessed an inversion was needed — it is not.)*
- **USB clock** — `init.c` already does crystal‑less HSI48 + CRS synced to USB.
- **Touch sensor** — auto‑detected via PB1; PB1 is unconnected on this board, so it
  reads "no touch" and falls back to the physical PA0 button automatically.
- **NFC / ATECC** — no NFC chip; SPI (PA5/6/7) and the AMS probe simply find nothing
  and NFC stays disabled → USB‑only. The ATECC (U2) is unused by this firmware.
  *(Note: the debug UART uses PB6/PB7, which are your I²C pins to the unused ATECC —
  harmless, since the firmware never talks to the ATECC.)*

See `git diff` in this folder for the exact patch.

---

## Cross‑platform: Windows, macOS, Linux

Nothing extra is needed in firmware — this builds a **standard FIDO2/U2F USB‑HID
authenticator** (FIDO HID usage page `0xF1D0`). That interface is recognized
natively by:

- **Windows 10/11** — via the built‑in WebAuthn API (browsers/Windows Hello). No driver.
- **macOS** — native (Safari/Chrome/Firefox WebAuthn).
- **Linux** — native in browsers.

The only host‑side extra is **Linux udev rules** so CLI tools (`nitropy`/`solo`) can
access the raw device without root (browsers don't need this). Create
`/etc/udev/rules.d/70-2fakey.rules`:

```
# Nitrokey FIDO2 / Solo (SoloKeys) — allow non-root access
SUBSYSTEM=="hidraw", ATTRS{idVendor}=="20a0", TAG+="uaccess"
KERNEL=="hidraw*", ATTRS{idVendor}=="20a0", TAG+="uaccess", MODE="0660"
```

then `sudo udevadm control --reload && sudo udevadm trigger`.

---

## Build

**Already built:** ready-to-flash images are in **`prebuilt/`** (`bootloader.hex`,
`solo.hex`, plus `.elf`/`.bin`), built unlocked (`FLASH_ROP=0`, `HWREV=2` → PA0,
`AES256=1`). App ≈ 59 KB flash / 30 KB RAM, bootloader ≈ 15 KB — fits the 256 KB part.

### Rebuild on Windows (Git Bash) — one command
The toolchain bundled with **STM32CubeIDE** (`arm-none-eabi-gcc` + `make`) is used;
no separate install needed. From Git Bash:
```bash
./build.sh
```
`build.sh` copies the tree to a space-free dir (the "2FA Key" path breaks GCC/Make),
puts the CubeIDE gcc/make on PATH, adds a `python3` shim, passes the version
explicitly (the native `make`'s `$(shell)` can't run under `sh`), builds, and copies
the results into `prebuilt/`.

### Manual equivalent (if you prefer)
```bash
# from a space-free copy of this repo, with CubeIDE gcc+make on PATH:
cd targets/stm32l432
V="VERSION=5.0.0 VERSION_FULL=5.0.0 VERSION_FULL_RAW=5.0.0.nitrokey \
VERSION_MAJ=5 VERSION_MIN=0 VERSION_PAT=0 SOLO_VERSION_FULL=5.0.0 SOLO_VERSION=5.0.0 \
SOLO_VERSION_MAJ=5 SOLO_VERSION_MIN=0 SOLO_VERSION_PAT=0 PAGESHR=256kB"
make cbor $V
make bootloader-nonverifying $V     # -> bootloader.hex
make all-hacker $V                  # -> solo.hex  (FLASH_ROP=0, unlocked)
```

### On WSL/Linux (clean, no workarounds)
On a real Linux env the stock flow works without the version overrides:
`sudo apt install gcc-arm-none-eabi make python3`, tag the repo
(`git tag -a 5.0.0.nitrokey -m x`), then `make cbor && make bootloader-nonverifying
&& make all-hacker`. The Docker path (`make docker-build-all`) also works there.

Both `bootloader.hex` and `solo.hex` are unlocked (no readout protection, SWD stays
open). Avoid the `--lock`/release merge until the device is final.

---

## Flash (first time, over SWD)

> **Flashing the raw `bootloader.hex` + `solo.hex` over SWD is NOT enough** — two
> flash markers that the Solo bootloader/tooling normally set are missing, so use the
> merged **`prebuilt/all.hex`** instead (full erase, flash it, reset):
> `STM32_Programmer_CLI -c port=SWD -e all -d all.hex -v -rst`
>
> `all.hex` = bootloader + app + the two fixes:
> 1. **Auth word @ `0x08035FF8` = `0x00000000`.** The bootloader only jumps to the app
>    when `is_authorized_to_boot()` sees this word == 0 (`AUTH_WORD_ADDR`). A raw SWD
>    flash leaves it `0xFFFFFFFF`, so the device stays in the **bootloader** — it still
>    shows up as a "fido" HID device but doesn't answer CTAP2, giving *"can't read your
>    security key."* (Normally the bootloader zeroes this itself when the app is
>    installed *through* it via `solo/nitropy program bootloader`.)
> 2. **Attestation key @ `0x08038800`** (the hacker key). Without a valid key here the
>    firmware's `device_migrate()` self-provisions a blank `0xFF` signing key and
>    MakeCredential fails. `all.hex` seeds the hacker key so migration installs the
>    matching hacker cert on first boot.
>
> After flashing, `fido_diag.py` (elevated) should report product **"Nitrokey FIDO2"**
> (not "…Bootloader") and a successful MakeCredential on button press.

Blank chip → use the ST‑Link (STLINK‑V3MINIE + TC2030‑CTX‑NL‑STDC14) path:

1. Power the board via its USB blade.
2. Hold the Tag‑Connect on J2.
3. In **STM32CubeProgrammer** (ST‑LINK / SWD): **Erase full chip**, then flash
   **both** `bootloader.hex` and `solo.hex` (base `0x08000000`), verify.

> ⚠️ Do **not** enable RDP/flash lock (no `--lock`, `FLASH_ROP=0`) yet — keep SWD
> open while bringing the board up. RDP2 is irreversible and kills SWD *and* DFU.

### After the first flash — update over USB (no ST‑Link)
The Solo/Nitrokey bootloader accepts USB updates: hold the button (PA0) while
plugging in to enter bootloader mode, then:
```bash
pip3 install nitropy         # or solo-python
nitropy fido2 util program bootloader solo.hex   # newer builds: nitropy start update
```

---

## Test

1. `chrome://webauthn` or <https://webauthn.io> → register + authenticate. Confirm
   the LED lights and that nothing completes until you press SW1 (user presence).
2. **Google**: Account → Security → 2‑Step Verification → security keys → add.
   Self‑built keys are accepted. ✅
3. **Microsoft**: personal accounts accept it; **Entra/M365 work tenants may reject**
   it where attestation is enforced (your key is self‑attested / not in the FIDO
   metadata service). See `../FIRMWARE_PORTING.md` §7 for details.

---

## Notes / possible refinements

- **LED behavior** is basic on/off (any non‑zero "color" → on). The reference
  "breathing" heartbeat therefore shows as steady/blink on a single LED; tune
  `led_rgb()` or the heartbeat in `device.c` if you want a specific pattern.
- **Button EXTI** (`init.c`) wakes on the PA0 rising edge (release). Presence is
  polled, so this is only relevant for sleep/wake; switch to falling edge if you add
  low‑power sleep.
- **Custom AAGUID / attestation**: the dev build uses a default self‑attestation
  identity. Set your own AAGUID if you want the key individually identifiable.

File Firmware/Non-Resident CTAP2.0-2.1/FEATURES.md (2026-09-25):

# 2FAK FIDO2 firmware - Phase 1 and 2 changes

This covers the identity and feature work done on the 2FA firmware. No hardware
change and no bootloader or RDP change. This is still the unlocked (RDP 0) build for
testing.

## Phase 1: identity and attestation

### Identity
- **AAGUID** set to the 2FAK product line: `c2aa81f8-352d-56e2-c689-2bfdb5a52ccc`.
  This is the public model id the key reports. It is defined in
  `targets/stm32l432/src/attestation.c` (`global_aaguid`).
- **Manufacturer** string changed from "Nitrokey" to **muru.global**.
- **USB VID/PID** changed to `0x1209 / 0x2FA2` (pid.codes range) so we no longer ship
  under Nitrokey's IDs. These are placeholders for pre-production. Request your own USB
  IDs before mass production.
- **Serial number** is already unique per unit (derived from the STM32 chip UID). No
  change needed. Check with `fido2-token -L` or `-I`.

### Attestation (muru.global batch key and certificate)
A batch attestation key and self-signed certificate were generated for muru.global,
with our AAGUID embedded in the certificate. Files live in `keys/2fak/`:
- `att_cert.pem` / `att_cert.der` - the certificate (public).
- `att_key.pem`, `priv.bin` - the **private** key. These are **gitignored** and must
  never be committed.

How it is used:
- `device_migrate()` was changed so it **respects an already-provisioned attestation
  page** instead of overwriting it. So a factory-injected muru key and cert are used.
- `provision_attestation.py` injects the key and cert into a built `all.hex` at flash
  time (the factory step). The private key goes only into the flashed image, not the
  repo.

```bash
pip install intelhex
python provision_attestation.py prebuilt/all.hex prebuilt/all_provisioned.hex
```

**For testing now:** if you flash the plain `prebuilt/all.hex` (not provisioned), the
key falls back to the public Solo/Nitrokey hacker certificate. The key still works for
registration and login (services that use "none" attestation, like Google, do not care).
Provision the muru cert when you want the key to attest as muru.global, and note that
getting that cert trusted (FIDO metadata service, certification) is a separate paid
process, not code.

## Phase 2: features

### LED language (already correct, now documented)
On this board the single LED gives clear feedback and needs no change:
- **Off** = idle, nothing to do.
- **Blinking** = the key is waiting for your touch (or is busy).
- **Solid on** = your touch was accepted.
- **Fast red-style bursts** = a reset or destructive action is in progress.

This matches how commercial keys behave (off until they need you). We kept the tested
button and presence state machine untouched.

### Extensions (verified enabled)
The firmware advertises and implements both:
- **hmac-secret** - lets the key derive a stable secret for a site or app. This is what
  enables the offline uses below.
- **credProtect** - lets a credential require the PIN before it can be used or listed.

Check on the device:
```bash
fido2-token -I <device>     # look for "extensions: credProtect, hmac-secret"
```

### SSH and Git signing (works today, no firmware change)
FIDO2 keys work as SSH keys with modern OpenSSH:
```bash
ssh-keygen -t ecdsa-sk -O resident -O application=ssh:2fak
# add the printed public key to the server's authorized_keys or GitHub
git config --global gpg.format ssh
git config --global user.signingkey ~/.ssh/id_ecdsa_sk.pub
git config --global commit.gpgsign true
```
You touch the key to log in or to sign a commit. "resident" stores it on the key so it
can be pulled onto a new computer.

### Offline secrets via hmac-secret
The key can act as a second factor for local encryption:
- **KeePassXC**: Database, Security, add a hardware key (challenge-response).
- **Disk encryption (Linux)**: `systemd-cryptenroll --fido2-device=auto /dev/...`.
- **File encryption**: `age-plugin-fido2-hmac`.

## Test checklist (after flashing)
1. `fido2-token -L` lists the key with the muru.global name and a unique serial.
2. `fido2-token -I` shows AAGUID `c2aa81f8...` and the two extensions.
3. Register and log in on webauthn.io and on Google.
4. Create an `ecdsa-sk` SSH key and log in to a server.
5. LED: off at idle, blinks when a site asks you to touch, solid after you touch.

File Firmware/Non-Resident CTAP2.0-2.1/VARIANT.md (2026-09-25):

# Non-resident (server-side) variant

This copy of the 2FA firmware is the **second-factor-only** product. It does not store
discoverable credentials (passkeys) on the device.

## What changed vs BACKUP
- `fido2/ctap.c` getInfo now advertises **`rk: false`** (no discoverable credential
  capability).
- `fido2/ctap.c` makeCredential **refuses** requests that ask for a resident key
  (returns `CTAP2_ERR_UNSUPPORTED_OPTION`), so relying parties fall back to a
  non-resident credential.
- No PIN is forced (unchanged). A pure second factor needs no PIN.

Everything else (identity, AAGUID, attestation provisioning, extensions, SSH,
hmac-secret) is the same as the Phase 1/2 firmware.

## ATECC608B hardware root (secure element)

The board's ATECC608B (I2C1 on PB6/PB7) can hold the FIDO root secret in tamper-
resistant hardware. When engaged, the MCU never stores the root: it asks the chip to
HMAC a per-device flash salt and uses the result as the master secret from which every
credential key is derived. The root key cannot be read out of the chip.

Files: `targets/stm32l432/src/atecc.{c,h}`. Hooks: `device_init()` calls `atecc_init()`
before state load; `crypto_load_master_secret()` re-derives the master from the chip
when it is ready.

**Safe by default / reflashable (RDP0).** `atecc_ready()` returns true only when the
chip is present *and* provisioned (config+data zones locked). On every un-provisioned
unit, or if the chip does not answer, the firmware falls back to the existing software
master secret with **no behaviour change**. So the current populated-but-unused chips
stay dormant and the MCU remains fully reflashable. The debug UART (which shares
PB6/PB7) is only built when `DEBUG_LEVEL > 0`; production builds leave the pins free
for I2C.

### Provisioning (one-time, IRREVERSIBLE) - sacrificial-unit flow

Provisioning is compiled only with `PROVISION=1` (`-DATECC_PROVISION`) and is never
automatic. It is triggered by a **button-gated** vendor command so it cannot fire by
accident. `atecc_provision()` runs these steps and returns the step it failed at
(`ATECC_PROV_*` in `atecc.h`):

1. write root-slot config (`SlotConfig[0]=0x2080`: IsSecret, HMAC-usable, immutable
   after lock; `KeyConfig[0]=0x003C`: non-ECC/generic key, lockable, ReqRandom=0)
2. **read the config back and verify** - if it mismatches, abort here; nothing is
   locked and the chip is still usable
3. lock the config zone *(irreversible)*
4. write a random 32-byte root key in the clear (allowed only while data unlocked)
5. lock the data zone *(irreversible)*
6. run a test derivation (Nonce passthrough + HMAC) and confirm it works

Steps 1-2 fail safe. The config values are set from the ATECC608B datasheet and
cryptoauthlib constants, but whether the HMAC command actually works with this config
can only be confirmed after locking - which is exactly why the first runs go on a
sacrificial unit with a logic analyzer on PB6/PB7.

Procedure:

    # 1. build + flash the provisioning image to a SACRIFICIAL board
    PROVISION=1 bash build.sh          # -> prebuilt/provision/all.hex
    #    flash prebuilt/provision/all.hex, replug
    python atecc_selftest.py           # confirm present:True first
    python atecc_provision.py          # type PROVISION, then TOUCH the key

    # 2. on success, go back to the normal image and check it took
    bash build.sh                      # -> prebuilt/all.hex (no provisioning cmd)
    #    flash prebuilt/all.hex, replug
    python atecc_selftest.py           # expect present:True ready:True kdf_ok:True

The normal image never contains the provisioning command. The I2C address (confirmed
0x60) and wake timing are already validated by the self-test.

### Self-test (confirm the chip is talking before you ever provision)

Vendor command `CTAPHID_ATECC` (0x63) probes the chip read-only and returns 9 bytes:
present, ready, config_locked, data_locked, 4-byte revision, kdf_ok. It never writes
to or locks the chip. It also queues an LED cue: **3 blinks** = present and
provisioned, **2 blinks** = present but not provisioned (normal today), **5 fast
blinks** = not answering.

Run it from an elevated terminal (`pip install fido2`):

    python atecc_selftest.py

Use this on a real board to confirm the I2C address (0x60 vs 0x6A) and wiring are
right *before* trusting the hardware root or attempting provisioning.

## Why
Best fit for non-technical users: password + touch, unlimited accounts, no PIN to
forget, no 50-key limit, no PIN-lockout resets, and nothing about your accounts stored
on the key.

## Test after flashing prebuilt/all.hex
1. `fido2-token -I` shows `options: ... rk: false`.
2. webauthn.io with "discoverable credential: discouraged" registers and logs in.
3. webauthn.io with "discoverable credential: required" should FAIL to register (this
   is correct: the device declines to store a passkey).
4. Google / GitHub: add as a security key (second factor). No PIN prompt.

To restore the full-featured build, flash `../BACKUP/prebuilt/all.hex`.

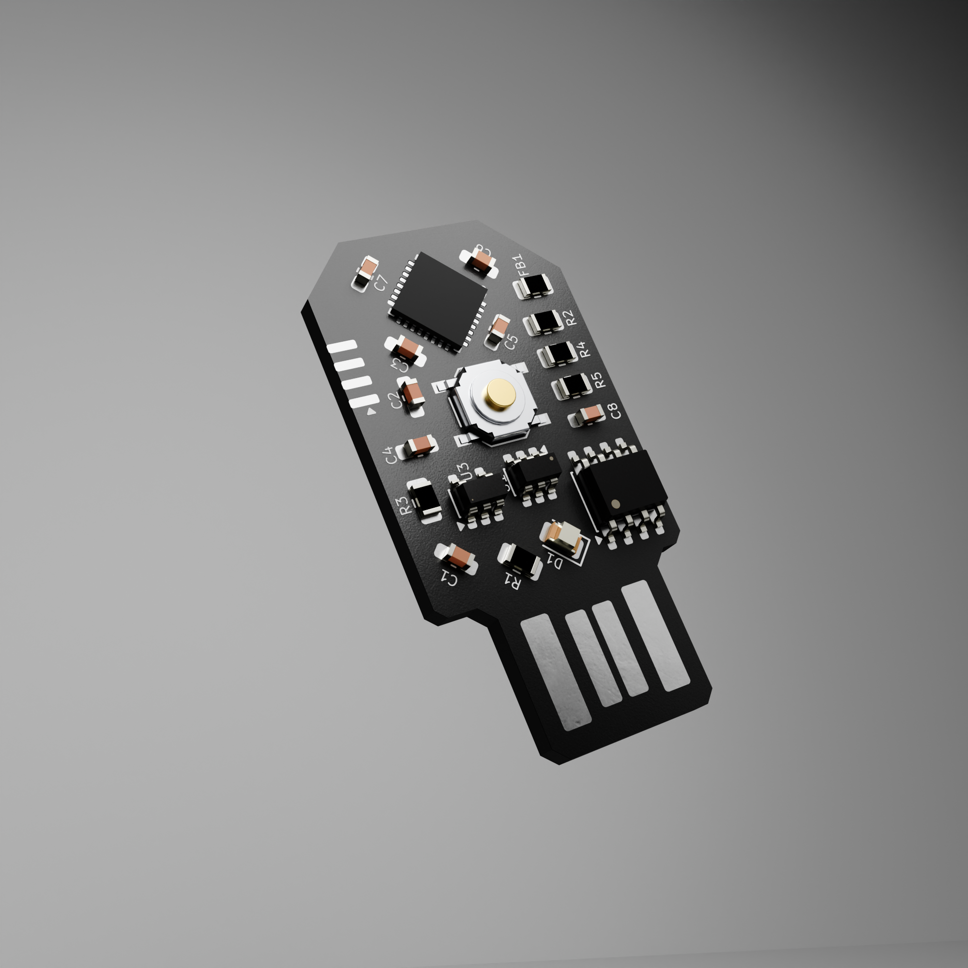
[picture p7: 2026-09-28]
Renders/2FAK-V1C-Render-2.png

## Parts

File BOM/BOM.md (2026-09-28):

# Bill of Materials

| Ref. | Qty. | Component | MPN | Footprint | Suppliers |
| :--- | ---: | :--- | :--- | :--- | :--- |
| **U1** | 1 | STM32L432KCU6 | `STM32L432KCU6` | QFN-32-1EP 5×5 | [Mouser](https://www.mouser.com/ProductDetail/STMicroelectronics/STM32L432KCU6?qs=dTJS0cRn7oiybcTRwI97Tw%3D%3D) · [DigiKey](https://www.digikey.ee/en/products/detail/stmicroelectronics/STM32L432KCU6/6132749) |
| **U2** | 1 | AP2112K-3.3 | `AP2112K-3.3TRG1` | SOT-23-5 | [Mouser](https://www.mouser.com/ProductDetail/Diodes-Incorporated/AP2112K-3.3TRG1?qs=x6A8l6qLYDDPYHosCdzh%2FA%3D%3D) · [DigiKey](https://www.digikey.ee/en/products/detail/diodes-incorporated/ap2112k-3-3trg1/4470746) |
| **U3** | 1 | ATECC608B | `ATECC608B-SSHDA-B` | SOIC-8 | [Mouser](https://www.mouser.com/ProductDetail/Microchip-Technology/ATECC608B-SSHDA-B?qs=W/MpXkg+dQ5IvpsOYxIilQ%3D%3D) · [DigiKey](https://www.digikey.ee/en/products/detail/microchip-technology/atecc608b-sshda-b/13415061) |
| **U4** | 1 | USBLC6-2SC6 | `USBLC6-2SC6` | SOT-23-6 | [Mouser](https://www.mouser.com/ProductDetail/STMicroelectronics/USBLC6-2SC6?qs=po45yt2pPpu%2FhNIlwQdTlg%3D%3D) · [DigiKey](https://www.digikey.ee/en/products/detail/shenzhen-slkormicro-semicon-co-ltd/usblc6-2sc6/28143029) |
| **SW1** | 1 | Tactile SMD | `611-PTS526SMG20S21LF` | XKB TS-1187A | [Mouser](https://www.mouser.ee/en/ProductDetail/611-PTS526SMG20S21LF) · [DigiKey](https://www.digikey.ee/en/products/detail/c-k/PTS526SK15SMTR2-LFS/10056626) |
| **D1** | 1 | Green LED | `APTD2012LZGCK` | 8050 | [Mouser](https://www.mouser.com/c/?q=APTD2012LZGCK) · [DigiKey](https://www.digikey.ee/en/products/detail/kingbright/aptd2012lzgck/7043078) |
| **R1, R2** | 2 | 10 kΩ 1% | `RC0805FR-0710KL` | 8050 | [Mouser](https://www.mouser.com/c/?q=RC0805FR-0710KL) · [DigiKey](https://www.digikey.ee/en/products/detail/stackpole-electronics-inc/RMCF0805FT10K0/1760676) |
| **R3** | 1 | 330 Ω 1% | `RC0805FR-07330RL` | 8050 | [Mouser](https://www.mouser.com/c/?q=RC0805FR-07330RL) · [DigiKey](https://www.digikey.ee/en/products/detail/yageo/RC0805FR-07330RL/727866) |
| **R4, R5** | 2 | 4.7 kΩ 1% | `RC0805FR-074K7L` | 8050 | [Mouser](https://www.mouser.com/c/?q=RC0805FR-074K7L) · [DigiKey](https://www.digikey.ee/en/products/detail/yageo/RC0805FR-074K7L/727929) |
| **R6** | 1 | 5.1 kΩ 1% | `RC0805FR-075K1L` | 8050 | [Mouser](https://www.mouser.ee/en/ProductDetail/YAGEO/RC0805FR-075K1L?qs=TvbiuNL4H85i1jCYhRJkKQ%3D%3D) · [DigiKey](https://www.digikey.ee/en/products/detail/yageo/RC0805FR-075K1L/727988) |
| **R7** | 1 | 5.1 kΩ 1% | `RC0805FR-075K1L` | 8050 | [Mouser](https://www.mouser.ee/en/ProductDetail/YAGEO/RC0805FR-075K1L?qs=TvbiuNL4H85i1jCYhRJkKQ%3D%3D) · [DigiKey](https://www.digikey.ee/en/products/detail/yageo/RC0805FR-075K1L/727988) |
| **FB1** | 1 | 600 Ω @ 100 MHz | `BLM21PG600SN1D` | 8050 | [Mouser](https://www.mouser.com/ProductDetail/Murata-Electronics/BLM21PG600SN1D?qs=LbqjZSvnDswFXSg06XQ50A%3D%3D) · [DigiKey](https://www.digikey.ee/en/products/detail/murata-electronics/BLM21PG600SN1D/584263) |
| **C1** | 1 | 4.7 µF 10V+ X5R | `CL10A475KP8NNNC` | 603 | [Mouser](https://www.mouser.com/c/?q=CL10A475KP8NNNC) · [DigiKey](https://www.digikey.ee/en/products/detail/samsung-electro-mechanics/cl10a475kp8nnnc/3886702) |
| **C2, C7** | 2 | 1 µF X7R | `CL10B105KB8NNNC` | 603 | [Mouser](https://www.mouser.com/c/?q=CL10B105KB8NNNC) · [DigiKey](https://www.digikey.ee/en/products/detail/samsung-electro-mechanics/CL10B103KB8NNNC/3886667) |
| **C3, C4, C5, C6, C8** | 5 | 100 nF X7R | `CL10B104KB8NNNC` | 603 | [Mouser](https://www.mouser.com/c/?q=CL10B104KB8NNNC) · [DigiKey](https://www.digikey.ee/en/products/detail/samsung-electro-mechanics/CL10B104JB8NNNC/3889119) |

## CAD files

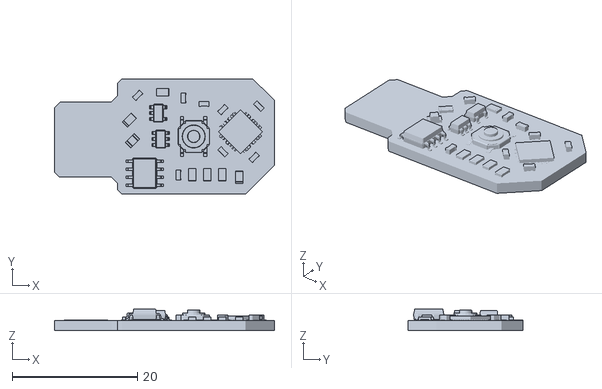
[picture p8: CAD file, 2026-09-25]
Hardware/3D/2FAK-V1B-sizing.stl
35.2 x 18.5 x 3.51

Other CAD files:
Hardware/3D/2FAK 3D Model.blend

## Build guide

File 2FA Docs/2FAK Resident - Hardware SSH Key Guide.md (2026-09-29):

# 2FAK Resident - Hardware SSH Key Guide

Using the **2FAK Passkey (Resident)** firmware as a hardware-backed SSH key, aimed at
system administrators who live in remote shells. The private key is generated on the
2FAK and never leaves it; every authentication needs a physical touch, so a stolen laptop
or a compromised jump host cannot use your key without the token in hand.

> This is a Passkey (Resident) firmware feature. Standard (non-resident) `ecdsa-sk` keys
> also work on the 2FAK Secure (Non-Resident) firmware, but the **portable / resident**
> keys described below (carry the key on the token, pull it onto any machine) require the
> Resident firmware, because they are discoverable credentials.

## What you get

- **Hardware-held SSH identity.** The private key lives in the 2FAK; `ssh` talks to it over
  the FIDO2 protocol. Nothing to exfiltrate from disk.
- **Touch-to-authorize every connection.** A compromised bastion cannot silently reuse the
  key while you are logged in.
- **Portable across machines.** A *resident* key is stored on the token and can be pulled
  onto any workstation with `ssh-keygen -K` - no key files to copy between machines.
- **Optional PIN (verify-required).** Force the device PIN in addition to touch for
  high-value hosts.
- **Bonus: Git signing.** The same key signs commits and tags.

## Requirements

- **OpenSSH 8.2 or newer** with FIDO/`libfido2` support on every machine you connect *from*.
  Check with `ssh -V`. (Servers you connect *to* only need 8.2+ to understand the
  `sk-ecdsa-sha2-nistp256@openssh.com` key type in `authorized_keys`.)
- A **2FAK Passkey (Resident)** key. The firmware supports **ES256**, so SSH uses the
  `ecdsa-sk` key type. `ed25519-sk` is **not** supported (the firmware has no Ed25519); use
  `ecdsa-sk`, which is cryptographically equivalent for this purpose.
- Linux/macOS: `libfido2` present (usually packaged with OpenSSH). Windows: see
  [Windows](#windows--putty).

Quick capability check (also available via the helper: `python 2FAK-ssh-enroll.py check`):

```bash
ssh -V                       # want OpenSSH_8.2 or newer
ssh-keygen -t ecdsa-sk -f /dev/null -C probe 2>&1 | grep -qi "unknown key type" \
  && echo "no -sk support" || echo "sk supported"
```

## 1. Enroll a resident (portable) key

A *resident* key stores the credential on the token itself, so you can reconstruct it on
any machine later. The local `id_ecdsa_sk_*` file is only a handle + public key - the
secret stays on the 2FAK.

```bash
ssh-keygen -t ecdsa-sk -O resident -O application=ssh:prod \
    -C "2fak:prod" -f ~/.ssh/id_ecdsa_sk_prod
# touch the 2FAK when the LED blinks
```

- `-O resident` - store the credential on the device (this is the portable part).
- `-O application=ssh:<label>` - the FIDO "relying party" string; **must start with `ssh:`**.
  Use distinct labels (`ssh:prod`, `ssh:lab`) if you want separate keys on one token.
- Add `-O verify-required` to force the **device PIN** in addition to touch (see
  [PIN tiering](#5-pin-tiering-touch-only-vs-pintouch)).

This produces `~/.ssh/id_ecdsa_sk_prod` (handle) and `~/.ssh/id_ecdsa_sk_prod.pub` (public
key). See [the helper CLI](#helper-cli-2fak-ssh-enroll) to do this and the backup key in
one guided flow.

## 2. Export a resident key onto a new machine

On a fresh admin workstation you do **not** copy key files around - you plug in the token
and pull the resident keys off it:

```bash
cd ~/.ssh
ssh-keygen -K            # writes id_ecdsa_sk_rk* for each resident key on the token
# touch the 2FAK (and enter the PIN if the key was enrolled verify-required)
```

Then reference the downloaded file with `ssh -i` or an `IdentityFile` line. This is the
workflow that makes the Passkey firmware attractive for admins who move between machines.

## 3. Install the public key on servers

For a handful of servers, append the `.pub` line to each server's `~/.ssh/authorized_keys`:

```bash
ssh-copy-id -f -i ~/.ssh/id_ecdsa_sk_prod.pub user@server
# or paste the single line from id_ecdsa_sk_prod.pub into authorized_keys by hand
```

The line is of type `sk-ecdsa-sha2-nistp256@openssh.com`. You can harden it with per-key
options, e.g. require the touch flag and pin the source:

```
# ~/.ssh/authorized_keys on the server
sk-ecdsa-sha2-nistp256@openssh.com AAAAInNr... 2fak:prod
```

### Fleet distribution with Ansible

For many servers, push the public key(s) with configuration management rather than by hand.
Distribute **both** the primary and backup public keys:

```yaml
# roles/ssh_hardware_keys/tasks/main.yml
- name: Install 2FAK hardware SSH keys for admins
  ansible.posix.authorized_key:
    user: "{{ admin_user }}"
    state: present
    key: "{{ item }}"
    exclusive: false
  loop:
    - "{{ lookup('file', 'files/id_ecdsa_sk_prod.pub') }}"
    - "{{ lookup('file', 'files/id_ecdsa_sk_prod_backup.pub') }}"
```

Rotating a key is then a one-line change in the vars/files and a playbook run.

## 4. Bastions and jump hosts (ProxyJump)

Admins rarely reach a server directly. Use **`ProxyJump`**, not agent forwarding - auth
happens locally on each hop and the key is never exposed on the intermediate host:

```
# ~/.ssh/config
Host bastion
    HostName bastion.example.net
    User admin
    IdentityFile ~/.ssh/id_ecdsa_sk_prod

Host prod-*
    ProxyJump bastion
    User admin
    IdentityFile ~/.ssh/id_ecdsa_sk_prod
```

```bash
ssh prod-web01     # you will be asked to touch the key for each hop
```

**Avoid `ForwardAgent yes` to untrusted hosts.** With a hardware key, touch-per-use already
limits misuse, but forwarding still exposes the agent socket on the intermediate machine;
`ProxyJump` sidesteps that entirely. If you must forward, scope it per-host and never to a
shared bastion.

## 5. PIN tiering (touch-only vs PIN+touch)

Match the friction to the value of the host:

| Tier | Enrollment | Login requires |
|---|---|---|
| Staging / lab | `-t ecdsa-sk -O resident` | touch |
| Production / privileged | add `-O verify-required` | **device PIN + touch** |

`verify-required` keys carry the requirement inside the credential, so the server can also
insist on it:

```
# authorized_keys on a production host - reject a key used without user verification
verify-required sk-ecdsa-sha2-nistp256@openssh.com AAAAInNr... 2fak:prod
```

Set/'change the device PIN with your normal FIDO2 tooling (e.g. the OS security-key
settings, or `fido2-token -S`). Standard CTAP retry limits apply: the key locks for the
session after repeated wrong PINs and blocks after the retry count is exhausted; a device
reset clears it (and destroys the resident keys).

## 6. SSH certificate authority (larger fleets)

Per-server `authorized_keys` does not scale to hundreds of hosts. The modern pattern is an
**SSH CA that issues short-lived user certificates**, with the 2FAK as the human root of
trust:

1. The admin authenticates to the CA / access proxy **with the 2FAK** (touch, and PIN on
   privileged roles).
2. The CA issues a **short-lived certificate** (e.g. 8 hours) scoped to the roles the admin
   is allowed to assume.
3. Servers trust the CA's public key (`TrustedUserCAKeys`), not individual admin keys, so
   revocation and audit are central.

This works with self-managed `ssh-keygen` CAs and with access platforms such as Teleport,
Smallstep `step-ca`, or HashiCorp Vault's SSH secrets engine. The 2FAK's role is the
same in all of them: the phishing-resistant, touch-required credential that gates
certificate issuance. Keep the CA signing key offline/HSM-backed; the 2FAK protects the
*human* step, not the CA itself.

## 7. Backup enrollment (do not skip)

The single most important operational rule: **enroll at least two 2FAK keys** and install
both public keys everywhere (authorized_keys, or register both with the CA). A hardware key
can be lost or damaged; without a backup you are one failure away from being locked out of
production.

- Enroll the primary, then enroll a backup with the **backup key inserted** (same
  `application` label, a different output file).
- Store the backup key physically separately (e.g. a safe).
- The [helper CLI](#helper-cli-2fak-ssh-enroll) prompts for the backup step by default.

## Windows / PuTTY

- **OpenSSH for Windows:** recent builds ship `-sk` support; use the same `ssh-keygen`
  commands from PowerShell. Ensure the OpenSSH version is 8.2+ (`ssh -V`).
- **PuTTY:** FIDO/security-key support was added in PuTTY 0.79+ (via `ssh-keygen`-created
  keys / Pageant). Import the `.pub`/handle as usual.
- **USB-A** is convenient on servers, KVM carts, and older admin hardware where USB-C or
  Bluetooth keys are awkward.

Reload load-time device gates after inserting the key if a tool does not detect it.

## Git commit and tag signing (bonus)

The same hardware key signs Git commits - useful for infrastructure-as-code repos:

```bash
git config --global gpg.format ssh
git config --global user.signingkey ~/.ssh/id_ecdsa_sk_prod.pub
git config --global commit.gpgsign true      # touch the key when committing
```

On GitHub, add the key under **Settings -> SSH and GPG keys** as **both** an authentication
key and a signing key.

## Limitations and honesty notes

- **Not for unattended automation.** A touch-required key cannot drive cron, CI, or Ansible
  runs on its own. Use the 2FAK for **interactive, privileged, human** sessions; keep
  automation on separate service credentials or short-lived certificates. (`no-touch-required`
  exists but defeats the purpose - avoid it.)
- **ES256 only.** `ecdsa-sk` is used; `ed25519-sk` is not supported by the firmware.
- **`-sk` keys are MCU-held.** The ATECC608B secure element backs the device's FIDO master
  secret on provisioned units; SSH `-sk` credentials themselves live in the MCU, not the
  secure element.
- **Self-tested conformance, not FIDO Certified.** See
  `2FAK Resident - FIDO Conformance Readiness.md`.

## Helper CLI: `2FAK-ssh-enroll`

`2FAK-ssh-enroll.py` (in this folder) is a thin, auditable wrapper around `ssh-keygen` that
guides the resident-key workflow and prompts you to enroll a backup key. It stores nothing
itself and does not talk to the device directly.

```bash
python 2FAK-ssh-enroll.py check                          # verify OpenSSH -sk support
python 2FAK-ssh-enroll.py enroll --name prod --verify-required
python 2FAK-ssh-enroll.py enroll --name lab --no-backup
python 2FAK-ssh-enroll.py export --dir ~/.ssh            # pull resident keys onto a new box
```

`enroll` creates a resident `ecdsa-sk` key (`--verify-required` adds the PIN requirement),
then offers to enroll a backup key with the same application label. `export` wraps
`ssh-keygen -K`. Everything it does can be done by hand with the commands earlier in this
guide.

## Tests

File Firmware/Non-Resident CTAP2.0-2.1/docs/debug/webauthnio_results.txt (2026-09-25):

_VgRxNQ2itjY...tghB7wBAEAAA
Description:
device-bound non-discoverable credential
Transports:
["ble", "nfc", "usb"]
Provider Information:
Name: (Unavailable)
AAGUID: 00000000-0000-0000-0000-000000000000

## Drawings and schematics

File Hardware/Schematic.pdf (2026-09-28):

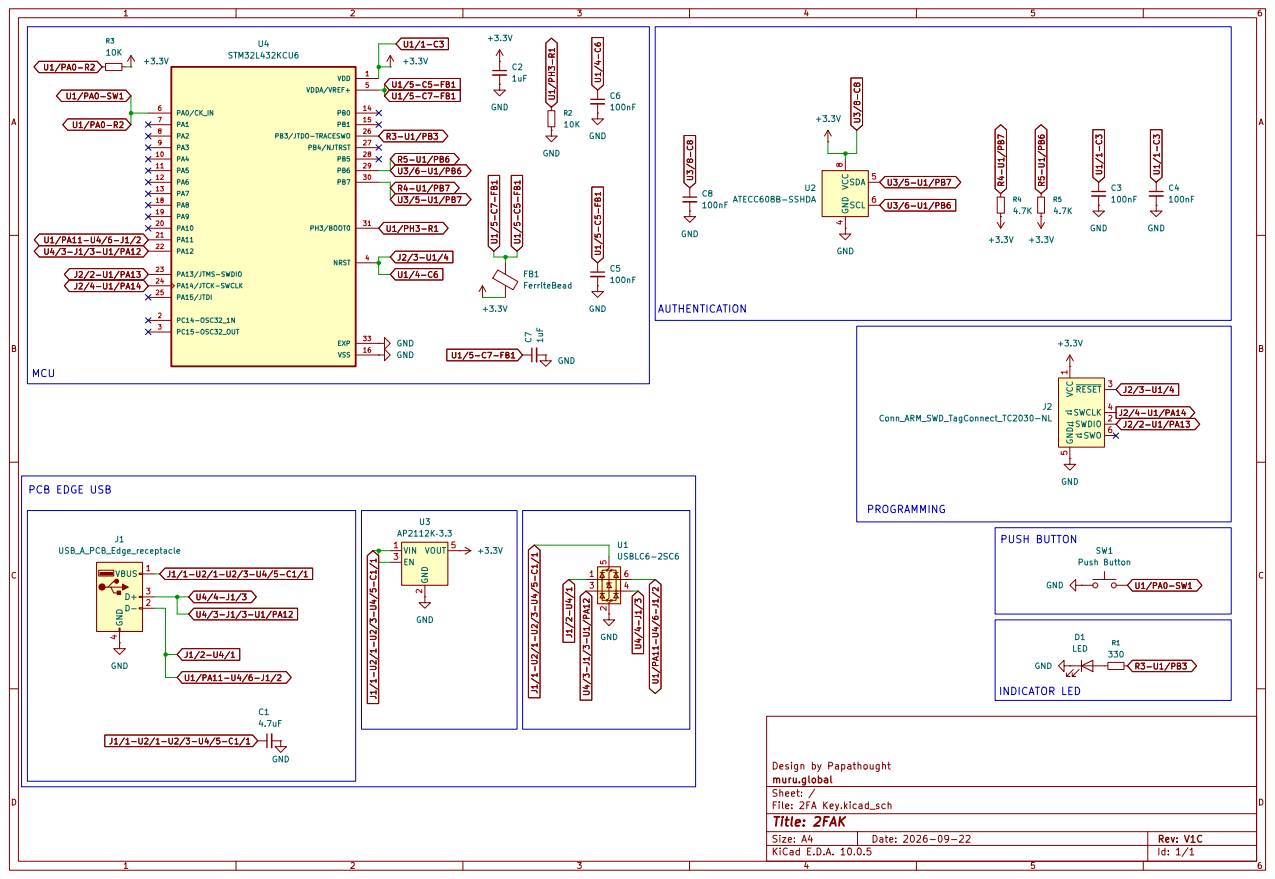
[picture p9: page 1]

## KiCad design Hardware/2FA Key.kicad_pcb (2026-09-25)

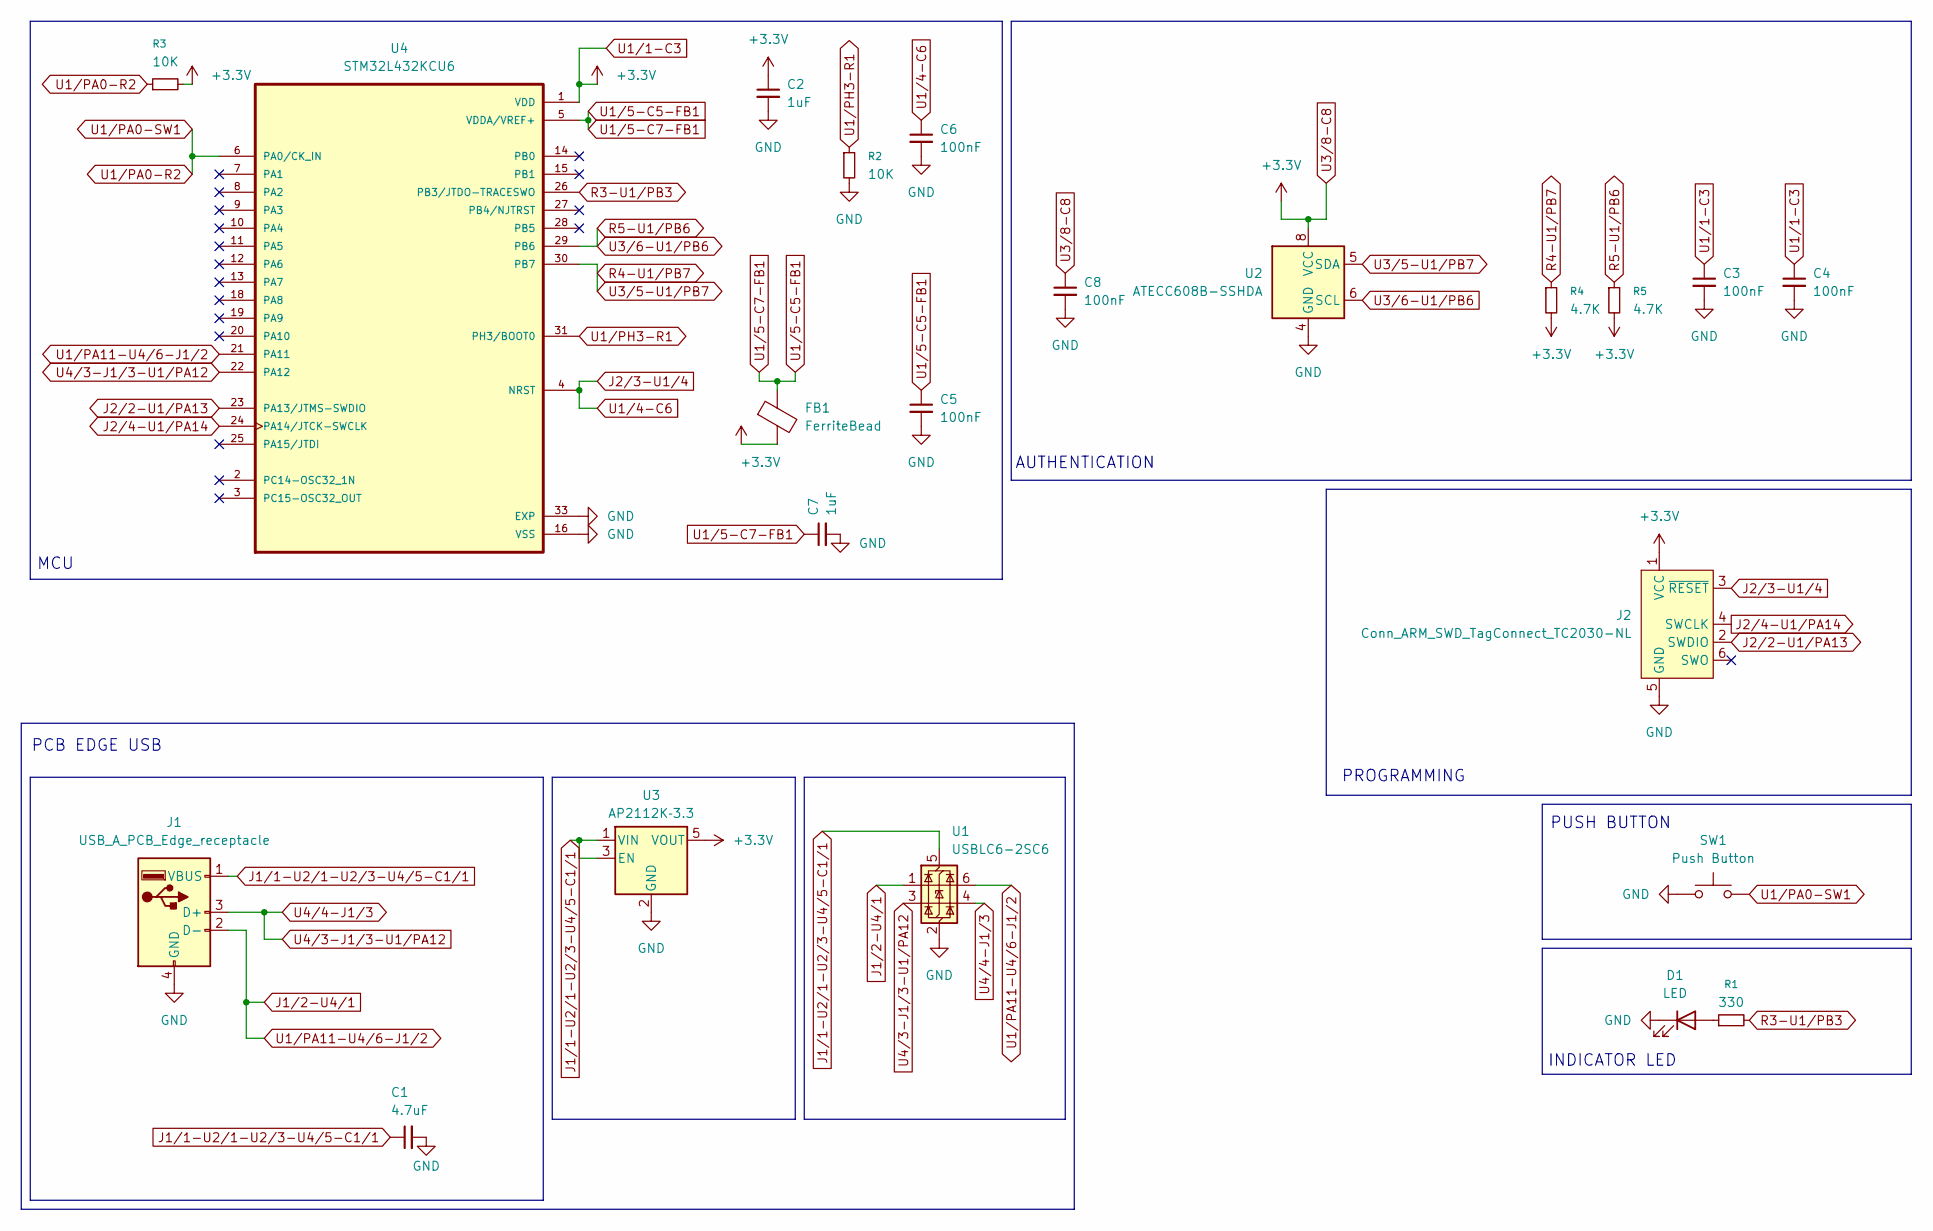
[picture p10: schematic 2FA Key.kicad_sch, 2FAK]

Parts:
C1: 4.7uF; C_0603_1608Metric_Pad1.08x0.95mm_HandSolder
C2, C7: 1uF; C_0603_1608Metric_Pad1.08x0.95mm_HandSolder
C3, C4, C5, C6, C8: 100nF; C_0603_1608Metric_Pad1.08x0.95mm_HandSolder
D1: LED; LED_0805_2012Metric
FB1: FerriteBead; R_0805_2012Metric
J1: USB_A_PCB_Edge_receptacle
J2: Conn_ARM_SWD_TagConnect_TC2030-NL; Tag-Connect_TC2030-IDC-NL_2x03_P1.27mm_Vertical
R1: 330; R_0805_2012Metric
R2, R3: 10K; R_0805_2012Metric
R4, R5: 4.7K; R_0805_2012Metric
SW1: Push Button; SW_Push_1P1T_XKB_TS-1187A
U1: USBLC6-2SC6; SOT-23-6
U2: ATECC608B-SSHDA; SOIC-8_3.9x4.9mm_P1.27mm
U3: AP2112K‑3.3; SOT-23-5
U4: STM32L432KCU6; QFN50P500X500X60-33N; PARTREV 3

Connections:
GND: C1.2, C2.2, C3.2, C4.2, C5.2, C6.2, C7.2, C8.2, D1.1 (K), J1.4 (GND), J2.5 (GND), R2.2, SW1.1, U1.2 (GND), U2.4 (GND), U3.2 (GND), U4.16 (VSS), U4.32 (VSS), U4.33 (EXP)
J1/1-U2/1-U2/3-U4/5-C1/1: C1.1, J1.1 (VBUS), U1.5 (VBUS), U3.1 (VIN), U3.3 (EN)
J1/2-U4/1: J1.2 (D-), U1.1 (I/O1), U1.6 (I/O1), U4.21 (PA11)
J2/2-U1/PA13: J2.2 (SWDIO), U4.23 (PA13/JTMS-SWDIO)
J2/3-U1/4: C6.1, J2.3 (~RESET), U4.4 (NRST)
J2/4-U1/PA14: J2.4 (SWCLK), U4.24 (PA14/JTCK-SWCLK)
unnamed: D1.2 (A), R1.1
R3-U1/PB3: R1.2, U4.26 (PB3/JTDO-TRACESWO)
R4-U1/PB7: R4.1, U2.5 (SDA), U4.30 (PB7)
R5-U1/PB6: R5.1, U2.6 (SCL), U4.29 (PB6)
U1/1-C3: C2.1, C3.1, C4.1, C8.1, FB1.2, J2.1 (VCC), R3.2, R4.2, R5.2, U2.8 (VCC), U3.5 (VOUT), U4.1 (VDD), U4.17 (VDD)
U1/5-C5-FB1: C5.1, C7.1, FB1.1, U4.5 (VDDA/VREF+)
U1/PA0-R2: R3.1, SW1.2, U4.6 (PA0/CK_IN)
U1/PH3-R1: R2.1, U4.31 (PH3/BOOT0)
U4/3-J1/3-U1/PA12: J1.3 (D+), U1.3 (I/O2), U1.4 (I/O2), U4.22 (PA12)

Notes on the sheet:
MCU
AUTHENTICATION
INDICATOR LED
PCB EDGE USB
PUSH BUTTON
PROGRAMMING

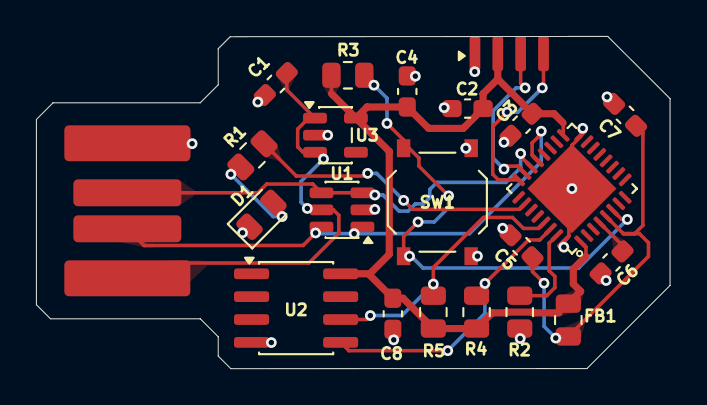
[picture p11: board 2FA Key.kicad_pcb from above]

Board: 2 copper layers, 35.2 x 18.5 mm, 21 parts (0 on the bottom side), 13 nets.

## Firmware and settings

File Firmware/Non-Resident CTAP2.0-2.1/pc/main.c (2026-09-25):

// Copyright 2019 SoloKeys Developers
//
// Licensed under the Apache License, Version 2.0, <LICENSE-APACHE or
// http://apache.org/licenses/LICENSE-2.0> or the MIT license <LICENSE-MIT or
// http://opensource.org/licenses/MIT>, at your option. This file may not be
// copied, modified, or distributed except according to those terms.
#include <stdio.h>
#include <stdlib.h>
#include <stdint.h>
#include <stdbool.h>
#include <unistd.h>
#include <time.h>

#include "cbor.h"
#include "device.h"
#include "ctaphid.h"
//#include "bsp.h"
#include "util.h"
#include "log.h"
#include "ctap.h"
#include "app.h"


void device_init(int argc, char *argv[]);
int usbhid_recv(uint8_t * msg);



int main(int argc, char *argv[])
{
    uint8_t hidmsg[64];

    set_logging_mask(
//        -1 |
		/*0*/
		// TAG_GEN|
		// TAG_MC |
		// TAG_GA |
		TAG_WALLET |
		TAG_STOR |
		TAG_BUTTON |
		//TAG_NFC_APDU |
		TAG_NFC |
		// TAG_CP |
		// TAG_CTAP|
		// TAG_HID|
		TAG_U2F|
		// TAG_PARSE |
		//TAG_TIME|
		// TAG_DUMP|
		// TAG_DUMP2|
		TAG_GREEN|
		TAG_RED|
        TAG_EXT|
        TAG_CCID|
		TAG_ERR
	);

    device_init(argc, argv);

    memset(hidmsg,0,sizeof(hidmsg));


    while(1)
    {

        if (usbhid_recv(hidmsg) > 0)
        {
            ctaphid_handle_packet(hidmsg);
            memset(hidmsg, 0, sizeof(hidmsg));
        }
        else
        {
        }

        ctaphid_check_timeouts();

        struct timespec ts;
        ts.tv_sec = 0;
        ts.tv_nsec = 1000*1000*10;
        nanosleep(&ts,NULL);
    }

    // Should never get here
    printf1(TAG_GREEN, "done\n");
    return 0;
}

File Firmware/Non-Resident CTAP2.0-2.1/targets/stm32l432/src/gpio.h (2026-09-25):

/*
 * Copyright (c) 2016, Conor Patrick
 * Copyright (c) 2018, Nitrokey UG
 * All rights reserved.
 *
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
 * THIS SOFTWARE IS PROVIDED BY THE COPYRIGHT HOLDERS AND CONTRIBUTORS "AS IS" AND
 * ANY EXPRESS OR IMPLIED WARRANTIES, INCLUDING, BUT NOT LIMITED TO, THE IMPLIED
 * WARRANTIES OF MERCHANTABILITY AND FITNESS FOR A PARTICULAR PURPOSE ARE
 * DISCLAIMED. IN NO EVENT SHALL THE COPYRIGHT OWNER OR CONTRIBUTORS BE LIABLE FOR
 * ANY DIRECT, INDIRECT, INCIDENTAL, SPECIAL, EXEMPLARY, OR CONSEQUENTIAL DAMAGES
 * (INCLUDING, BUT NOT LIMITED TO, PROCUREMENT OF SUBSTITUTE GOODS OR SERVICES;
 * LOSS OF USE, DATA, OR PROFITS; OR BUSINESS INTERRUPTION) HOWEVER CAUSED AND
 * ON ANY THEORY OF LIABILITY, WHETHER IN CONTRACT, STRICT LIABILITY, OR TORT
 * (INCLUDING NEGLIGENCE OR OTHERWISE) ARISING IN ANY WAY OUT OF THE USE OF THIS
 * SOFTWARE, EVEN IF ADVISED OF THE POSSIBILITY OF SUCH DAMAGE.

 */

#ifndef GPIO_H_
#define GPIO_H_

#include <stdbool.h>

#define BUTTON_MIN_PRESS_T_MS    1000
#define BUTTON_VALID_CONSUMED_T_MS    (10*1000)
#define BUTTON_MAX_PRESS_T_MS    (3*1000)

#define BUTTON_MIN_PRESS_T_MS_EXT    (5*1000)
#define BUTTON_MAX_PRESS_T_MS_EXT    (8*1000)

// set time after the power on, during which a single U2F or configuration
// request would be accepted
#define SELF_ACCEPT_MAX_T_MS    (2*1000)

#define LED_BLINK_T_ON           ((uint16_t) (LED_BLINK_PERIOD/2))                                 // ms
#define LED_BLINK_T_OFF          ((uint16_t) (led_blink_period_t - led_blink_ON_t))  // ms
#define LED_BLINK_PERIOD         ((uint16_t) 780)                                 // ms
#define LED_BLINK_NUM_INF        255


#define U2F_MS_CLEAR_BUTTON_PERIOD			(20*1000)
#define U2F_MS_INIT_BUTTON_PERIOD			(500)

void button_manager (void);
uint8_t button_get_press (void);
uint8_t button_get_press_extended (void);

uint8_t button_press_in_progress(void);
uint8_t button_press_is_consumed(void);
void _clear_button_press(bool forced);
void clear_button_press();

// debug / status functions
uint8_t last_button_cleared_time_delta();
uint8_t last_button_pushed_time_delta();

void led_on (void);
void led_off (void);
bool led_is_blinking(void);
void stop_blinking(void);
void led_blink (uint8_t blink_num, uint16_t period_t);
void led_blink_manager (void);
void led_change_ON_time(uint16_t ON_time);

typedef enum {
	BST_INITIALIZING,			// wait for the charge to settle down
	BST_INITIALIZING_READY_TO_CLEAR,	// ready for clearing
	BST_META_READY_TO_USE,			// META state (never used), to ease testing,
								// if button is ready (e.g. >READY) or not (<READY)
	BST_UNPRESSED,				// ready to use
	BST_PRESSED_RECENTLY,		// touch registration is started
	BST_PRESSED_REGISTERED,		// touch registered, normal press period
	BST_PRESSED_REGISTERED_TRANSITIONAL,		// touch registered, normal press, but timeouted
	BST_PRESSED_REGISTERED_EXT, // touch registered, extended press period
	BST_PRESSED_REGISTERED_EXT_INVALID, // touch registered, extended press period, invalidated
    BST_PRESSED_CONSUMED_ACTIVE,		// BST_PRESSED_CONSUMED, but accepts requests
	BST_PRESSED_CONSUMED,		// touch registered and consumed, button still not released, does not accept requests

	BST_MAX_NUM
} BUTTON_STATE_T;

BUTTON_STATE_T button_get_press_state (void);
uint8_t button_get_press (void);

bool is_in_first_10_seconds(void);
bool button_ready_to_work(void);
void set_button_awaiting_up(const bool awaits);

void led_reset_default_color(void);
void led_set_default_color(uint32_t color);
char * button_state_to_string(BUTTON_STATE_T state);
void led_set_proper_color_for_expected_state(BUTTON_STATE_T b);
void button_press_set_consumed(BUTTON_STATE_T target_button_state);

#endif /* GPIO_H_ */

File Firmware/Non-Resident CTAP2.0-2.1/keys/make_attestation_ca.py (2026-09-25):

#!/usr/bin/env python3
"""
Generate the 2FAK attestation PKI: a self-signed attestation Root CA and a batch
attestation leaf certificate signed by it, for FIDO2 "packed" (basic_full) attestation.

Outputs (into keys/2fak/):
  ca_key.pem     Root CA private key           (SECRET - gitignored)
  ca_cert.pem    Root CA certificate           (public; goes in the metadata statement)
  ca_cert.der    Root CA cert, DER
  root_b64.txt   base64(DER root cert)         (paste into attestationRootCertificates)
  att_key.pem    Leaf (batch) private key      (SECRET - gitignored)
  priv.bin       Leaf private scalar, 32 bytes (SECRET - used by provision_attestation.py)
  att_cert.pem   Leaf certificate              (public; embedded in the device, sent as x5c)
  att_cert.der   Leaf cert, DER

The leaf certificate carries the FIDO AAGUID extension (1.3.6.1.4.1.45724.1.1.4) whose
value MUST equal the authenticator's AAGUID (from keys/2fak/aaguid.hex and the firmware),
or attestation validation fails.

Run once to establish the CA. Re-running overwrites everything (new keys), which would
invalidate already-provisioned devices - so keep ca_key.pem safe and back it up.

    python keys/make_attestation_ca.py
"""
import os, base64, datetime
from cryptography import x509
from cryptography.x509.oid import NameOID, ExtensionOID
from cryptography.hazmat.primitives import hashes, serialization
from cryptography.hazmat.primitives.asymmetric import ec

HERE = os.path.dirname(os.path.abspath(__file__))
OUT = os.path.join(HERE, "2fak")
AAGUID_OID = x509.ObjectIdentifier("1.3.6.1.4.1.45724.1.1.4")

# Subject identity. OU MUST be exactly "Authenticator Attestation" for FIDO packed attestation.
COUNTRY = "SI"
ORG = "muru.global"
LEAF_CN = "muru.global 2FAK Series"
ROOT_CN = "muru.global 2FAK Attestation Root CA"

def aaguid_bytes():
    hexstr = open(os.path.join(OUT, "aaguid.hex")).read().strip()
    b = bytes.fromhex(hexstr)
    assert len(b) == 16, "aaguid.hex must be 16 bytes"
    return b

def save(name, data, binary=False):
    path = os.path.join(OUT, name)
    if isinstance(data, str):
        data = data.encode()
    with open(path, "wb") as f:
        f.write(data)
    return path

def main():
    os.makedirs(OUT, exist_ok=True)
    aaguid = aaguid_bytes()
    now = datetime.datetime.utcnow()
    far = now + datetime.timedelta(days=365 * 25)

    # --- Root CA ---
    ca_key = ec.generate_private_key(ec.SECP256R1())
    ca_name = x509.Name([
        x509.NameAttribute(NameOID.COUNTRY_NAME, COUNTRY),
        x509.NameAttribute(NameOID.ORGANIZATION_NAME, ORG),
        x509.NameAttribute(NameOID.COMMON_NAME, ROOT_CN),
    ])
    ca_cert = (x509.CertificateBuilder()
        .subject_name(ca_name).issuer_name(ca_name)
        .public_key(ca_key.public_key())
        .serial_number(x509.random_serial_number())
        .not_valid_before(now).not_valid_after(far)
        .add_extension(x509.BasicConstraints(ca=True, path_length=0), critical=True)
        .add_extension(x509.KeyUsage(digital_signature=False, key_cert_sign=True,
                                     crl_sign=True, key_encipherment=False,
                                     content_commitment=False, data_encipherment=False,
                                     key_agreement=False, encipher_only=False,
                                     decipher_only=False), critical=True)
        .add_extension(x509.SubjectKeyIdentifier.from_public_key(ca_key.public_key()), critical=False)
        .sign(ca_key, hashes.SHA256()))

    # --- Leaf (batch) attestation cert ---
    leaf_key = ec.generate_private_key(ec.SECP256R1())
    leaf_name = x509.Name([
        x509.NameAttribute(NameOID.COUNTRY_NAME, COUNTRY),
        x509.NameAttribute(NameOID.ORGANIZATION_NAME, ORG),
        x509.NameAttribute(NameOID.ORGANIZATIONAL_UNIT_NAME, "Authenticator Attestation"),
        x509.NameAttribute(NameOID.COMMON_NAME, LEAF_CN),
    ])
    # AAGUID extension value is a DER OCTET STRING wrapping the 16 raw bytes.
    aaguid_ext_value = b"\x04\x10" + aaguid
    leaf_cert = (x509.CertificateBuilder()
        .subject_name(leaf_name).issuer_name(ca_name)
        .public_key(leaf_key.public_key())
        .serial_number(x509.random_serial_number())
        .not_valid_before(now).not_valid_after(far)
        .add_extension(x509.BasicConstraints(ca=False, path_length=None), critical=True)
        .add_extension(x509.UnrecognizedExtension(AAGUID_OID, aaguid_ext_value), critical=False)
        .add_extension(x509.AuthorityKeyIdentifier.from_issuer_public_key(ca_key.public_key()), critical=False)
        .sign(ca_key, hashes.SHA256()))

    # --- write outputs ---
    save("ca_key.pem", ca_key.private_bytes(serialization.Encoding.PEM,
        serialization.PrivateFormat.TraditionalOpenSSL, serialization.NoEncryption()))
    save("ca_cert.pem", ca_cert.public_bytes(serialization.Encoding.PEM))
    ca_der = ca_cert.public_bytes(serialization.Encoding.DER)
    save("ca_cert.der", ca_der, binary=True)
    save("root_b64.txt", base64.b64encode(ca_der).decode() + "\n")

    save("att_key.pem", leaf_key.private_bytes(serialization.Encoding.PEM,
        serialization.PrivateFormat.TraditionalOpenSSL, serialization.NoEncryption()))
    save("att_cert.pem", leaf_cert.public_bytes(serialization.Encoding.PEM))
    save("att_cert.der", leaf_cert.public_bytes(serialization.Encoding.DER), binary=True)
    # 32-byte raw private scalar for provision_attestation.py
    save("priv.bin", leaf_key.private_numbers().private_value.to_bytes(32, "big"), binary=True)

    print("AAGUID:", aaguid.hex())
    print("Root CA subject:", ROOT_CN)
    print("Leaf subject:", leaf_name.rfc4514_string())
    print("Wrote CA + leaf into", OUT)
    print("attestationRootCertificates (base64 DER) is in keys/2fak/root_b64.txt")

if __name__ == "__main__":
    main()

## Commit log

2026-09-25 Initial 2FAK monorepo: non-resident + resident firmware, docs, licensing, pid.codes
    Reorganise into a public-ready structure:
    - Firmware/Non-Resident CTAP2.0-2.1 (second-factor) and Firmware/Resident CTAP2.3 (passkey)
    - Dual Apache-2.0 OR MIT license, NOTICE crediting Nitrokey/SoloKeys upstream
    - Docs, conformance logs, and pid.codes PID allocation request
    - .gitignore keeps all private keys and provisioned images out of the repo
2026-09-25 Resident: signed USB firmware-update path (step 3)
    - Generate a muru production bootloader signing key (keys/make_bootloader_key.py);
    private key kept in gitignored secrets/, public key embedded in the verifying
    bootloader's pubkey_bootloader.c (replacing the Nitrokey prod key).
    - build.sh VERIFY_BOOT switch: dev (non-verifying, unsigned USB updates) vs production
    (verifying, signed only). Emits all-dev.hex and all-verifying.hex.
    - Tools/updater/2fak_update.py: self-contained USB updater for 0x1209/0x2FA2 (CTAPHID
    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
2026-09-25 updater: robust device discovery (VID/PID or sole FIDO device); note Windows admin requirement
2026-09-25 fix: verifying build must use RELEASE=1 so the production (muru) bootloader key is embedded, not the NK test key; updater 'info' reads+compares the on-device bootloader pubkey
2026-09-25 fix: place .ARM.exidx before .flag so firmware_version is the last 4 bytes of the app
    The bootloader reads the uploaded version from last_written-4. GCC was placing .ARM.exidx
    after .flag (orphan section), so the version marker was not last and USB updates were
    rejected as rollbacks (0x27). Now .flag is the final flash section.
2026-09-25 step 2: production RDP-2 / SWD lockdown tooling + docs (Resident)
    The firmware already self-programs RDP-2 on boot when the persistent lock flag is set
    (flash_option_bytes_init -> solo_is_locked; vendor cmd 0x99 sets the flag). Add:
    - updater 'lock' subcommand: sets the flag (with an irreversibility confirmation), then
    the device applies RDP-2 on the next power cycle. 'info' now reports lock status.
    - Docs/Production Lock (RDP-2, SWD).md: mechanism, mandatory ordering, warnings, and a
    sacrificial-unit validation procedure.
    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
2026-09-25 Non-Resident CTAP2.0/2.1: derive from Resident codebase, resident features off
    Replace the stale non-resident base with the production Resident codebase built with
    RESIDENT=0 (no rk/credMgmt, rk=true rejected) and FIDO23 off (caps at FIDO_2_1). It now
    inherits every fix: PAGES=128 layout, .ARM.exidx-before-.flag, boot-lock-on-reset,
    PIN_AUTH_INVALID, the verifying bootloader + our production key, VERIFY_BOOT, and the
    RDP-2 lockdown. Metadata regenerated for the second-factor profile. Shares the bootloader
    signing key and (for now) the attestation identity with Resident.
    [ctap.c, ctap.h, make_bootloader_key.py]
2026-09-25 updater: tolerate mid-reboot enumeration errors during device discovery
    find_device now opens each HID device individually and skips ones that raise (e.g.
    'Wrong channel' while the 2FAK is switching app<->bootloader), instead of letting the
    exception crash the re-enumeration wait loop. Callers retry, so a transient miss is fine.
2026-09-25 Add flashing-station operator tool (Tools/flashing-station)
    Tkinter wizard implementing the 10-step production flow: detect ST-Link probes, select
    units, assign firmware (variant + dev/prod), confirm, flash via STM32_Programmer_CLI with a
    live log, run firmware-appropriate USB tests (getInfo/options/AAGUID/ES256/ATECC), mint a
    unique ID (from the MCU UID) with QR + Code128 barcode, and append to a never-overwritten
    master CSV log. Backends station_core.py (programmer/flash/UID/codes/log) and
    station_tests.py (USB FIDO tests). Runtime logs/codes are gitignored. RDP-2 locking stays a
    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
2026-09-25 gitignore Docs/ (keep documentation private, out of the public repo)
    [2FA Key.kicad_pcb, 2FA Key.kicad_sch, 2FAK 3D Model.blend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]
2026-09-25 pid.codes: correct submission structure (org/muru.global + 1209/2FA2/index.md)
    Fix the PID entry to the howto format: 1209/2FA2/index.md with layout:pid, title, owner,
    license, source (was a name-only file at the wrong path). Add org/muru.global/index.md and
    PID_CODES_SUBMISSION.md. Remove the old pidcodes/ template and stray attempts.
2026-09-28 Added Schematic and V1A photo
    Schematic.pdf represents current components and wiring.
    V1A photo in /Photos/ directory. V1B and V1C photos will be uploaded on next batch arrival.
2026-09-28 docs: product/firmware documentation set; Apache-2.0 relicense; pid.codes 2FA2 registered
    - Add hardware/firmware/conformance docs and product listings for both SKUs
    - Relicense to Apache-2.0 only (drop MIT); update README and firmware READMEs
    - Record pid.codes PID 0x2FA2 as approved/registered
    - Add Schematic.pdf, product photo and renders; add BOM.md
    - Remove pid.codes submission scaffolding (merged upstream) and LICENSE/LICENSE-MIT
    - gitignore and untrack KiCad .kicad_prl UI state, .blend1 autosave, internal HANDOFF notes
2026-09-29 docs: readable README with board visuals; SSH guide + helper
2026-10-13 Reorganize repo and rewrite README; add Ed25519 and compliance/programmable content
    Move SSH guide to Guides/ and FIDO/RoHS docs to Compliance/; add Programmable/ (HID Injection, Mouse Jiggler, hardware, case), 3D Printable/, BOM datasheets, renders. Rewrite README around 2FAK V1C a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
